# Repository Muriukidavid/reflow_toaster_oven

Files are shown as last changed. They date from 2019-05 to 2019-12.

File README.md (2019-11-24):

 
This is a reflow oven controller based on tinyK22 board with NXP K22P121M120SF7RM MCU.

The goal is to use the board on a breadboard for developing the firmware and design a custom board 

### Prototype Schematic
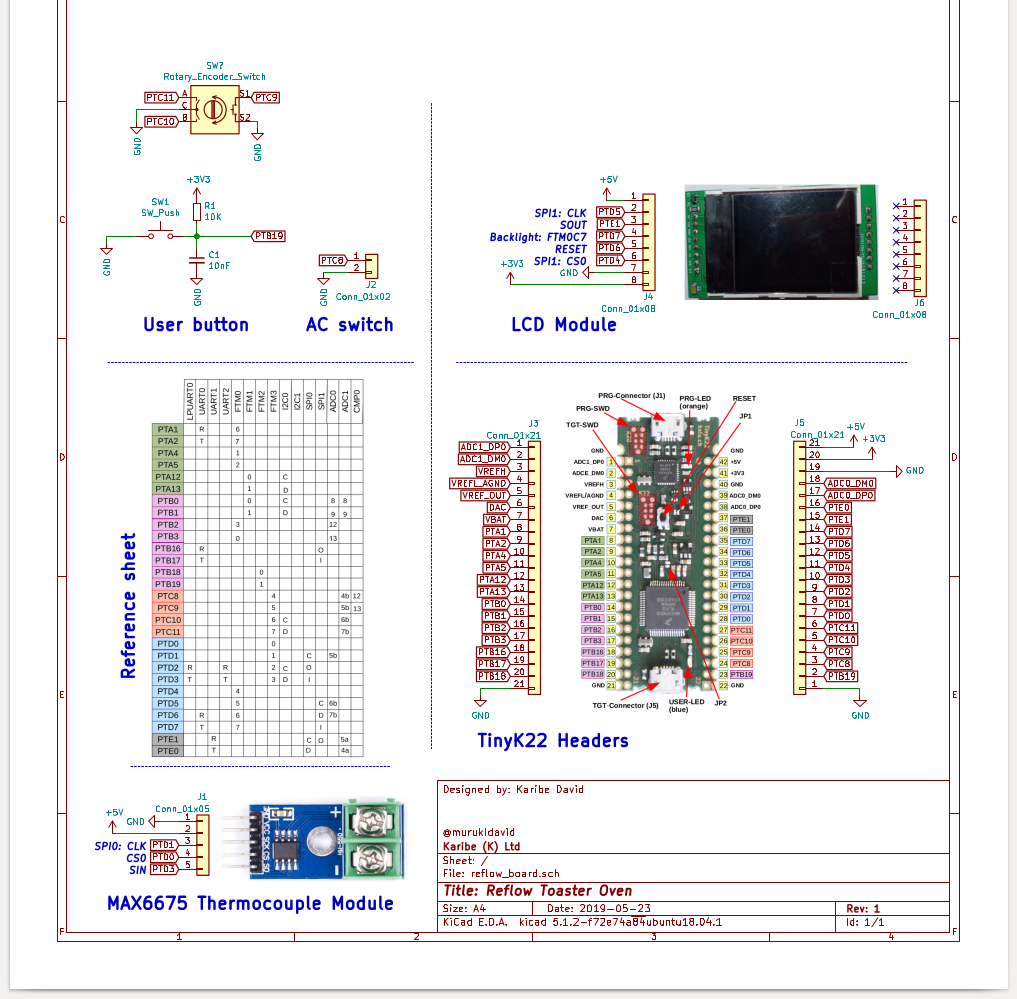
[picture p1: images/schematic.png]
The schematic


### Bread Board Prototype
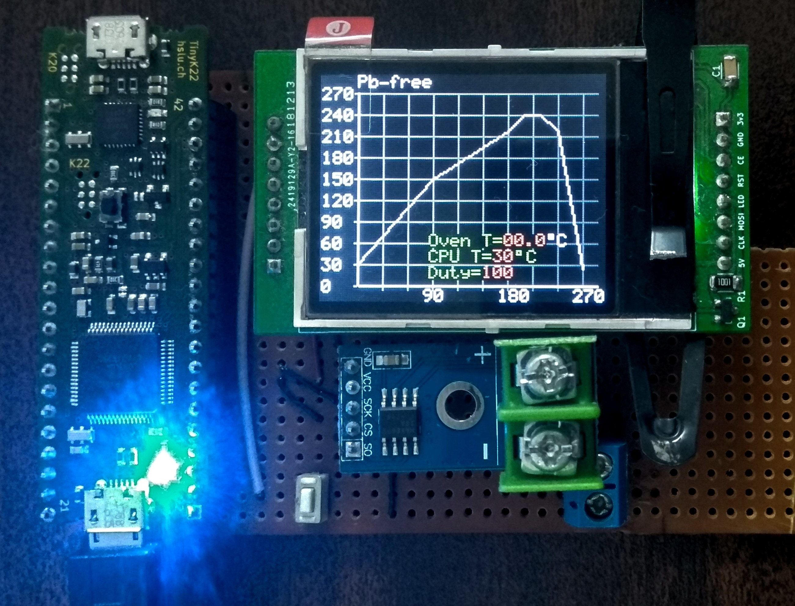
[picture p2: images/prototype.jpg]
The rough prototype testing board


### Custom Board Schematic
<!-- ![The schematic](images/schematic_custom.png)-->
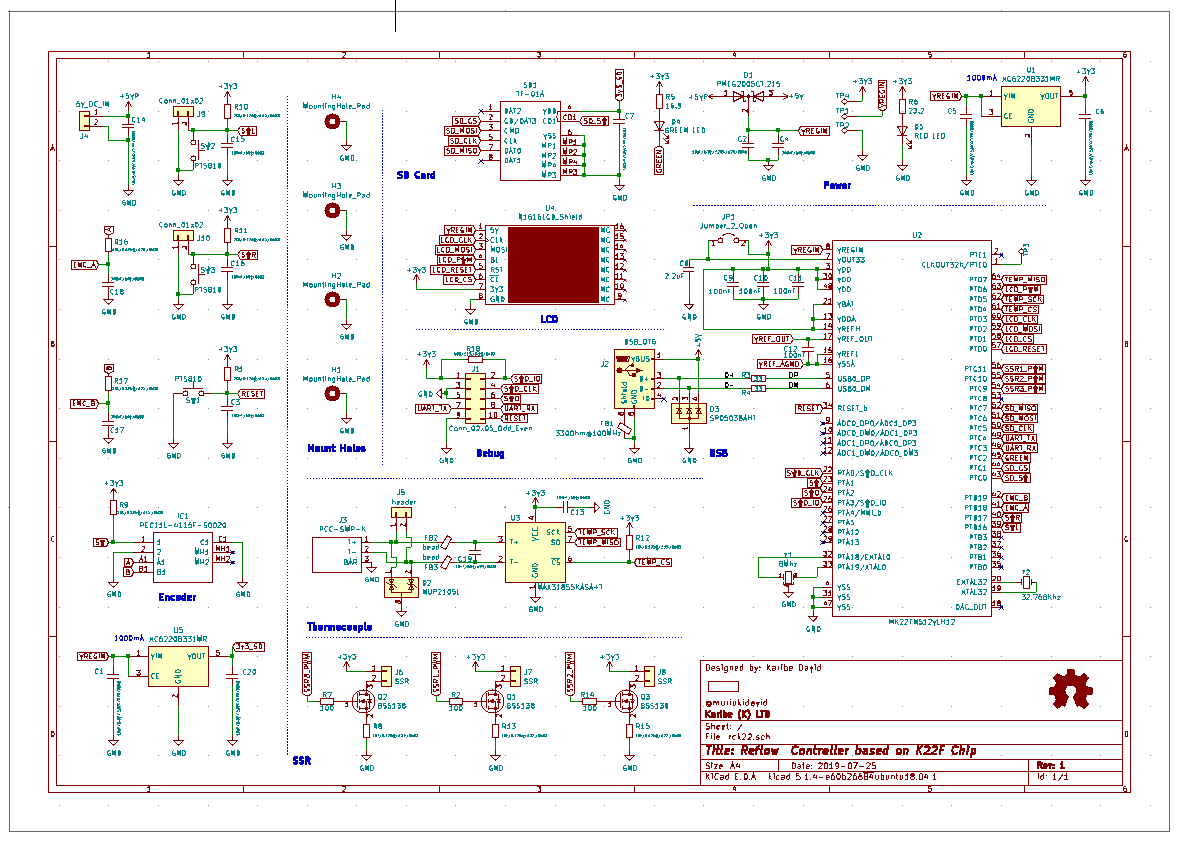
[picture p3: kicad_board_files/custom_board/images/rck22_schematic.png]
The custom board schematic


### Custom Board Top View 

A preview of the ongoing Custom board PCB design
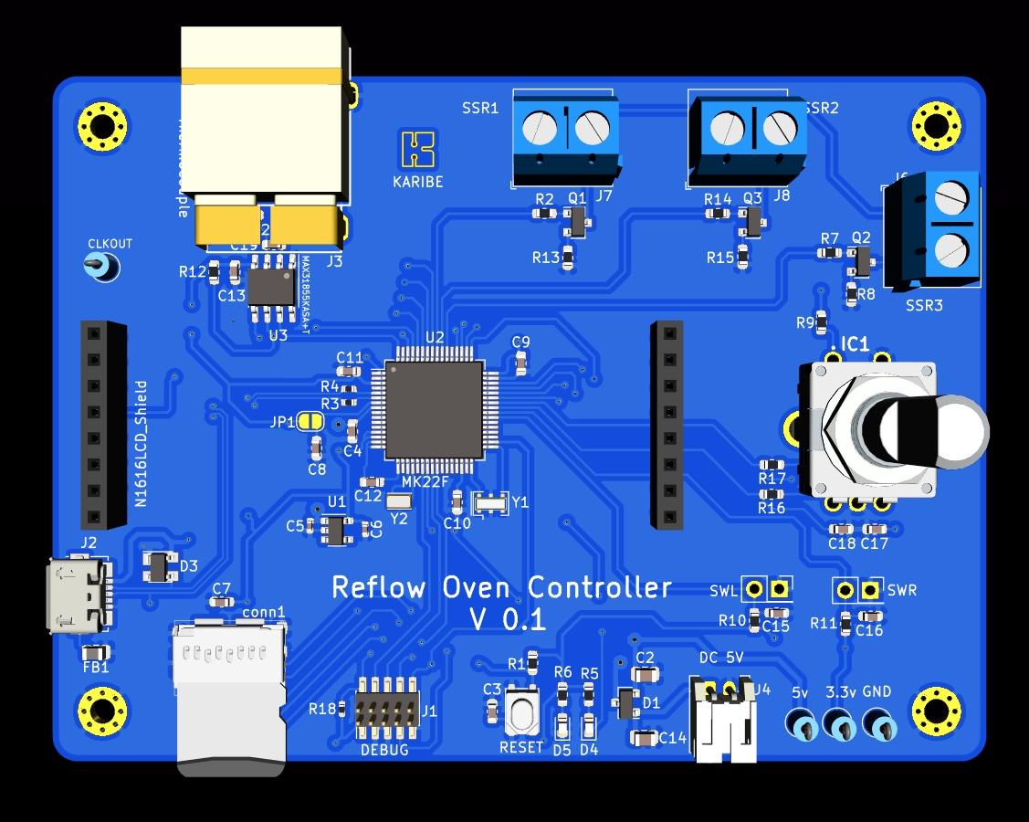
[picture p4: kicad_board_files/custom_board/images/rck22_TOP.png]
Board top view


A 3D preview of the current design
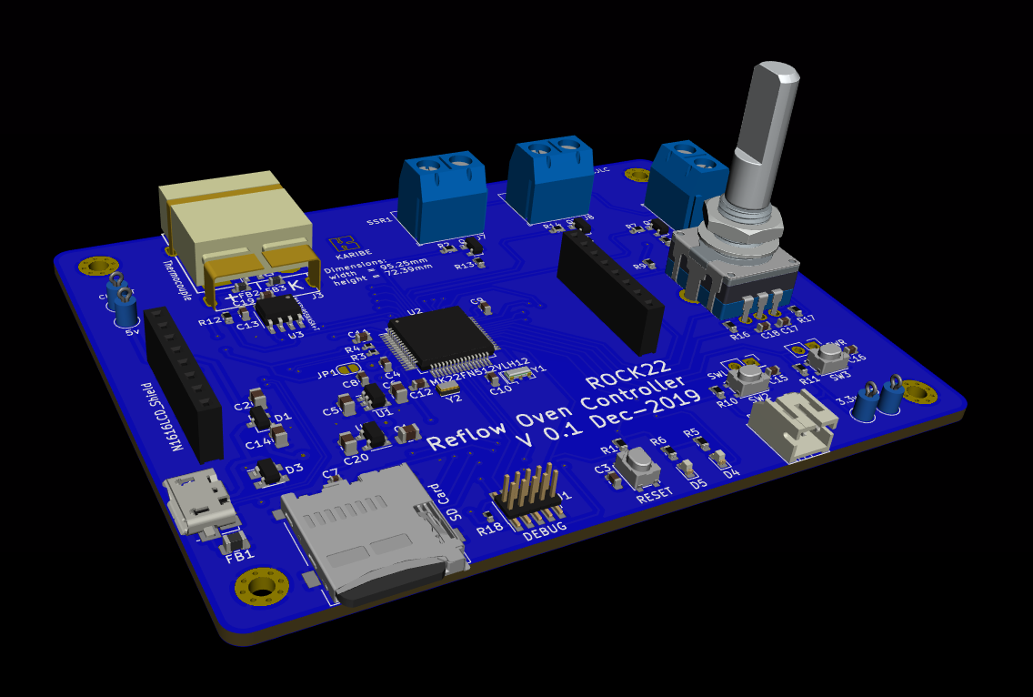
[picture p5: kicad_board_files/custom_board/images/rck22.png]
ISO 3D view PCB layout


### BOM
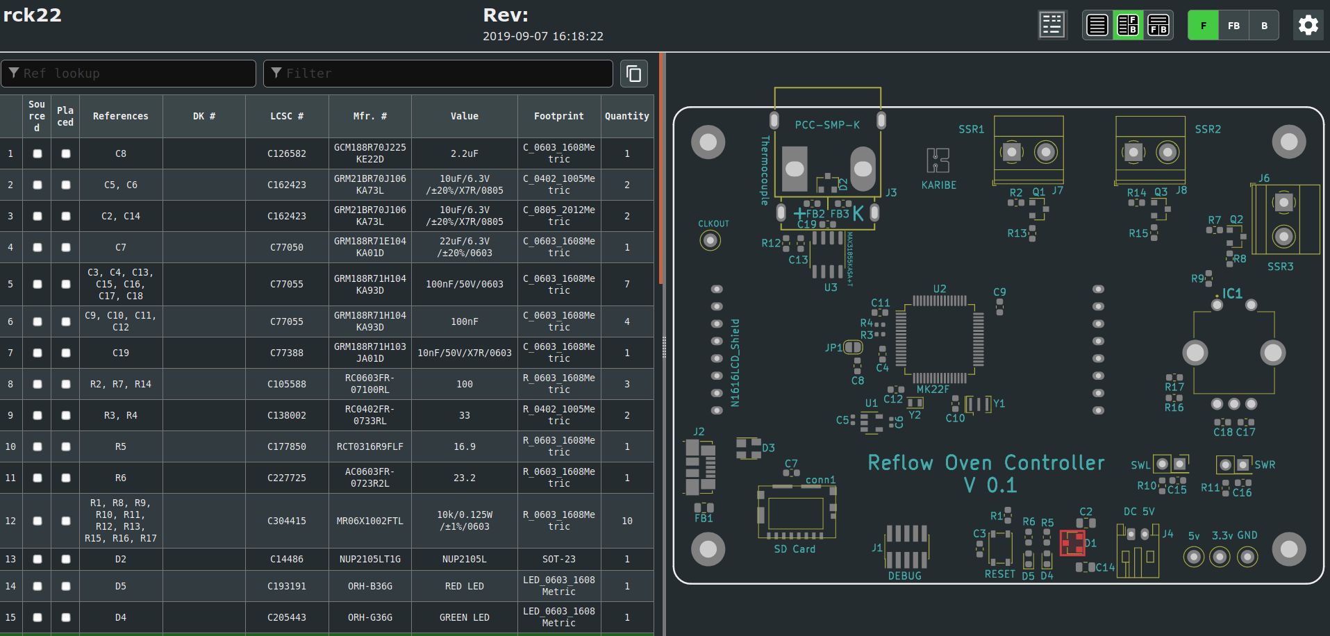
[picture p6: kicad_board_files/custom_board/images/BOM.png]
BOM
<a href="https://htmlpreview.github.io/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" rel="BOM">

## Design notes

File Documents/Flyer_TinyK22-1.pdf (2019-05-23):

# TinyK22

## Rev A

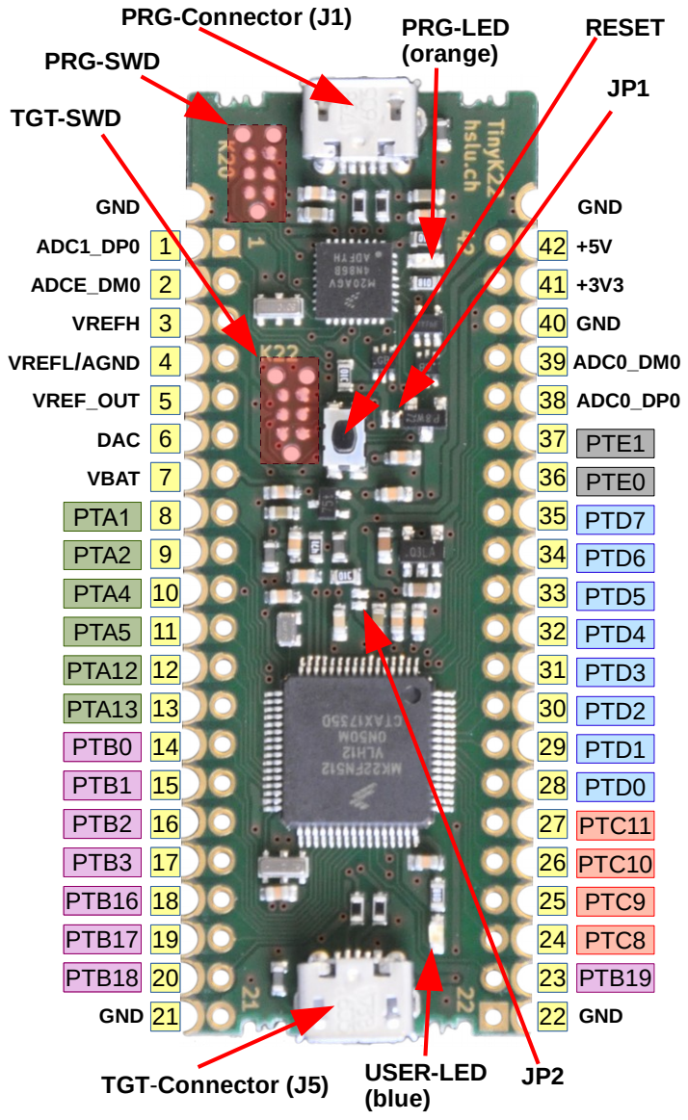
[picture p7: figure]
PTB0; PTB2; PTB1; PTB3; PTB17; PTB16; PTB18; ADC1_DP0; ADCE_DM0; VREFL; /AGND; VREFH; VREF_OUT; DAC; VBAT; PTA2 PTA4; PTA12; PTA5; PTA13; PTA1; GND; ADC0_DM0; ADC0_DP0; PTB19; PTC11 PTC10; PTC8; PTC9; PTD7 PTD6 PTD5; PTD3; PTD4; PTD2 PTD1 PTD0; PTE1 PTE0; TGT; -Connector (J5); PRG-Connector (J1); USER-LED (blue); PRG-LED (orange); RESET; TGT-SWD; PRG-SWD

# TinyK22

## Rev A

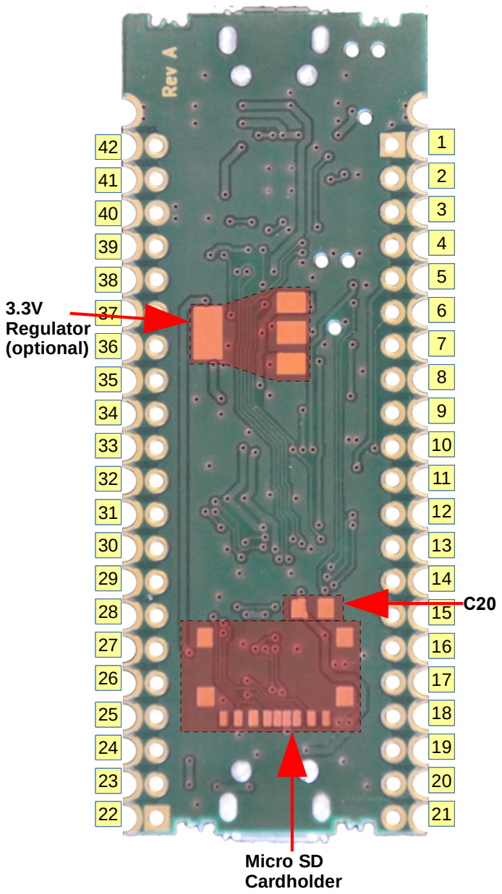
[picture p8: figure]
3.3V Regulator (optional); Micro SD Cardholder

PTA1 | R | 6
PTA2 | T
PTA4

PTA12

PTA5

PTA13

PTE1 | R | | 5a
PTE0 | T | D | 4a

PTD7
PTD6
PTD5

PTD3

PTD4

PTD2
PTD1

PTC11

PTD0

PTC10

PTC9

PTB19

LPUART0
UART0
FTM0
FTM1

FTM3
ADC0

ADC1

CMP0

UART1

UART2
FTM2
I2C0

I2C1

FTM2
SPI0

SPI1

CMP0

PTB0

PTB2 | 3 | 12 0 13
PTB3

PTB1

PTB17

PTB16

PTB18

PTD7
PTD6

PTD3
PTD2
PTD1
PTD0

PTD7
PTD6

PTD3

PTD2
PTD16

PTD5

PTD1

PTD0

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
PTC8
4 | 4b 5 | 5b 6 | 6b 7 | 7b

PTD7

PTD5

PTD2

PTD4

01 | 5b

R

R

2
T

T

3
45 | 6b

R

6 | 7b
T

7

# CDCD IO

12
13
CD

C
CD
OI | CDI C | O

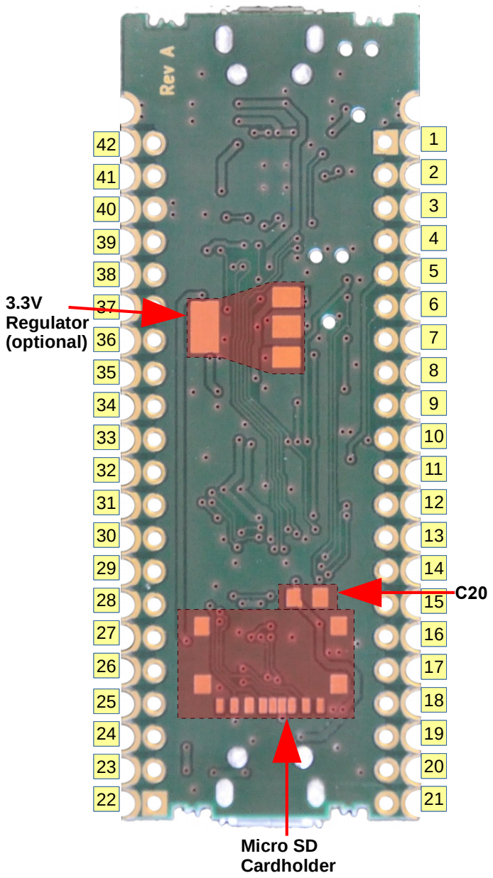
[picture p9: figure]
3.3V Regulator (optional); Micro SD Cardholder
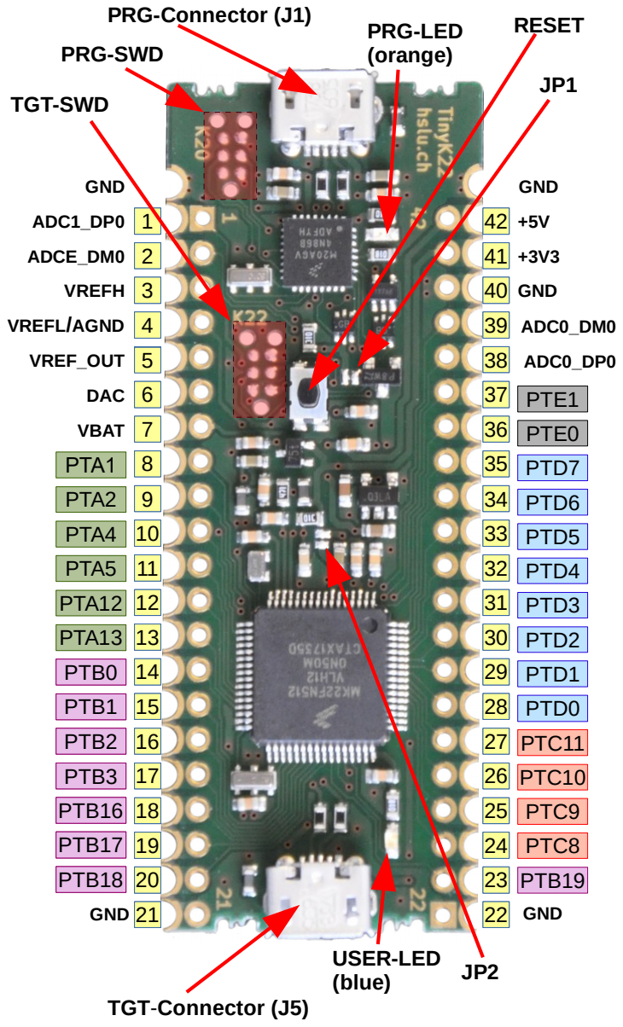
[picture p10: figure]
PTB0; PTB2; PTB1; PTB3; PTB17; PTB16; PTB18; ADC1_DP0; ADCE_DM0; VREFL; /AGND; VREFH; VREF_OUT; DAC; VBAT; PTA2 PTA4; PTA12; PTA5; PTA13; PTA1; GND; PTB19; PTC11 PTC10; PTC8; PTC9; PTD7; PTD6 PTD5; PTD3; PTD4; PTD2 PTD1 PTD0; PTE1 PTE0; TGT; -Connector (J5); PRG-Connector (J1); USER-LED (blue); PRG-LED (orange); RESET; ADC0_DM0; ADC0_DP0; TGT-SWD; PRG-SWD

PTA1 | R | 6
PTA2 | T
PTA4 | | 712

PTA12

PTA5

PTA13

PTE1

PTD7

PTE0

PTD6 PTD6 PTD6 PTD1 | | | | | C
PTD5 PTD2 | R | R | 2 | CD

PTD3

PTD4

PTD2
PTD1

PTC11

PTD0

PTC10

PTC9

PTB19

LPUART0
UART0
FTM0

FTM1

FTM3

ADC0

ADC1

CMP0

UART1

UART2
FTM2
I2C0
I2C1

FTM2
SPI0

SPI1

CMP0

PTB0

PTB2

PTB1

PTB3
PTB16 | RT
PTB17
PTB18

PTD7

PTD3
PTD2
PTD1
PTD0

PTD7

PTD3

PTD2
PTD16

PTD5

PTD0

TR | 5a

010

8

8
1
9

9
3 | 12 0 | 13

01

PTC8
4 | 4b 5 | 5b 6 | 6b 7 | 7b

PTD7

PTD5

PTD4

01 | 5b

T

T

3
45 | 6b

R

6 | 7b
T

7

# CDCD IO

12
13
CD
OI | CDI C | O D | 4a

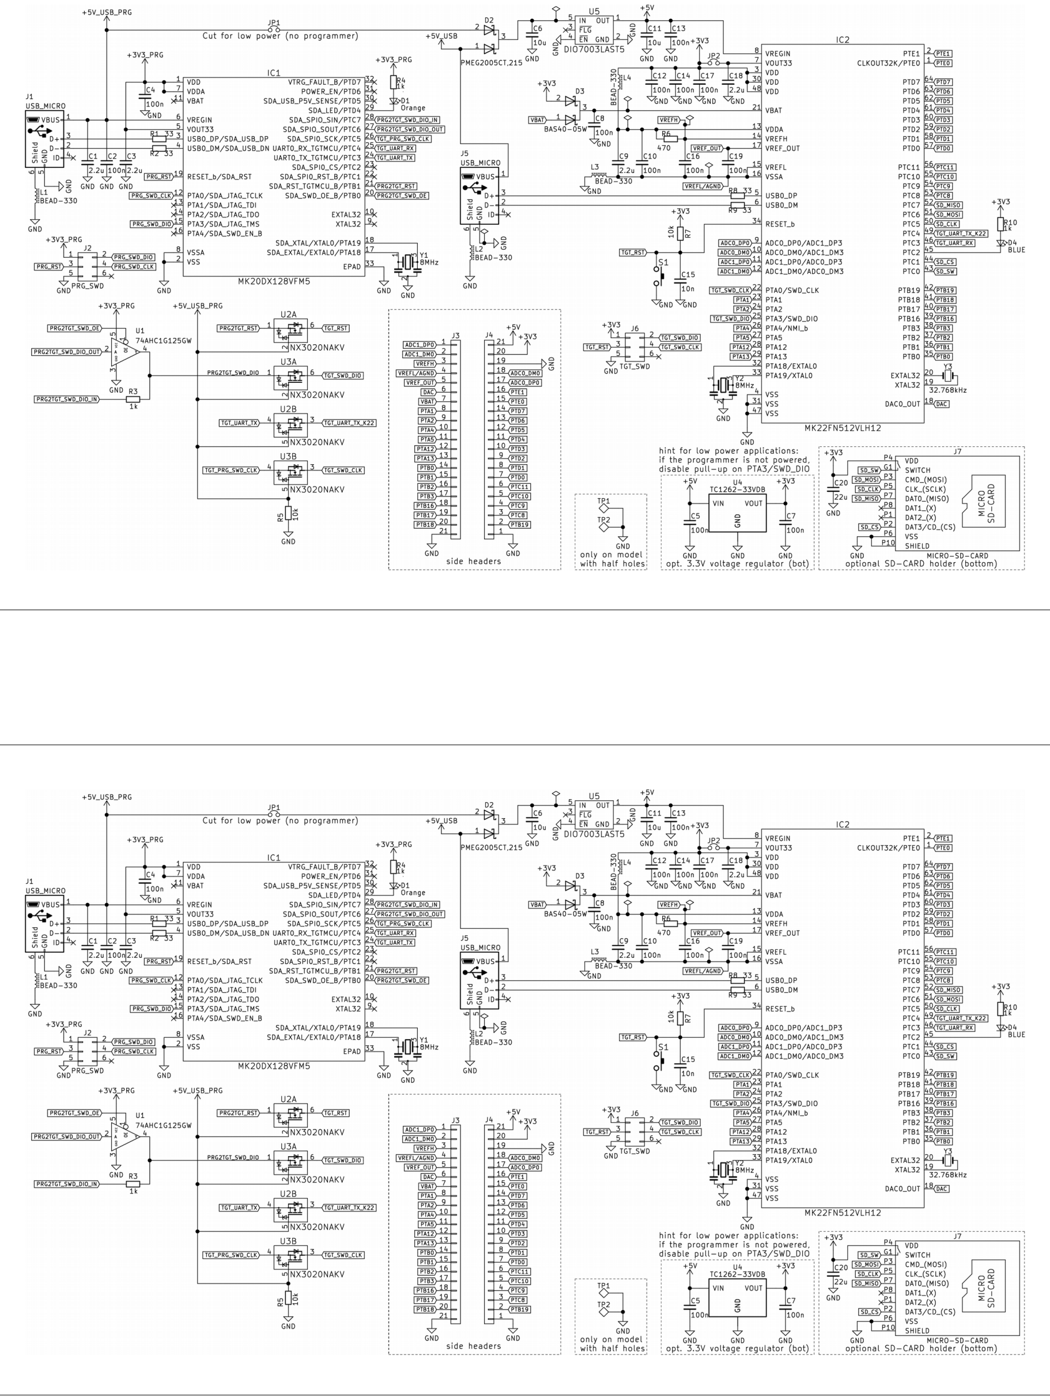
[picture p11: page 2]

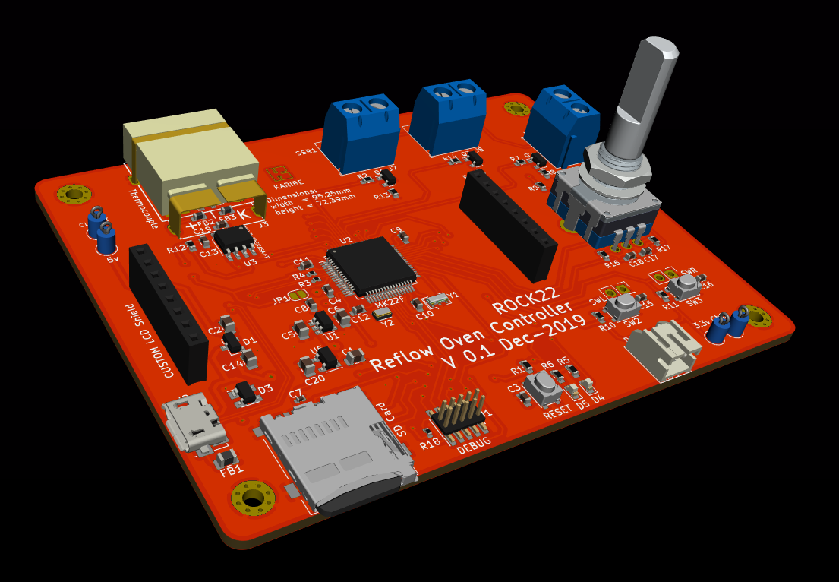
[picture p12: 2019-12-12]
kicad_board_files/custom_board/images/rck22_orange.png

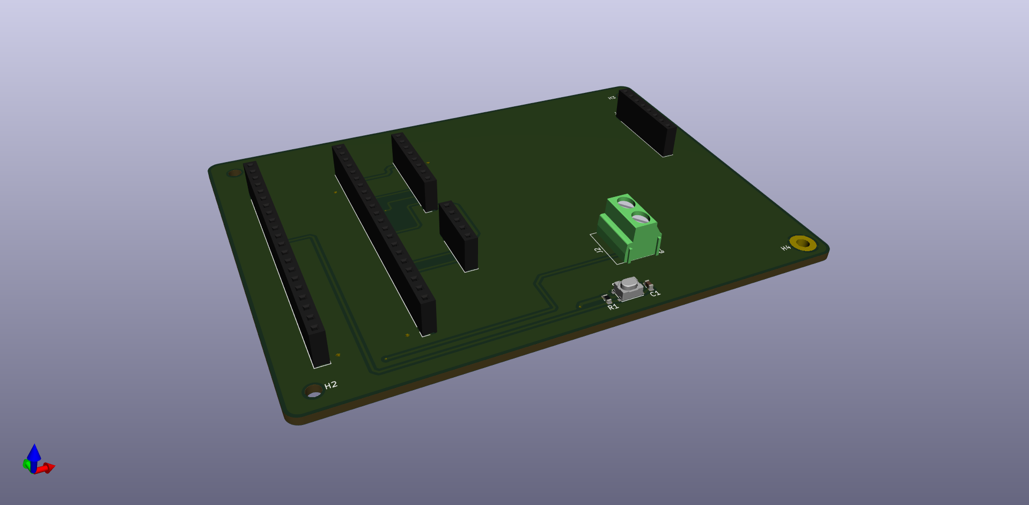
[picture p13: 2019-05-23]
kicad_board_files/tinyK22_board/images/reflow_board.png

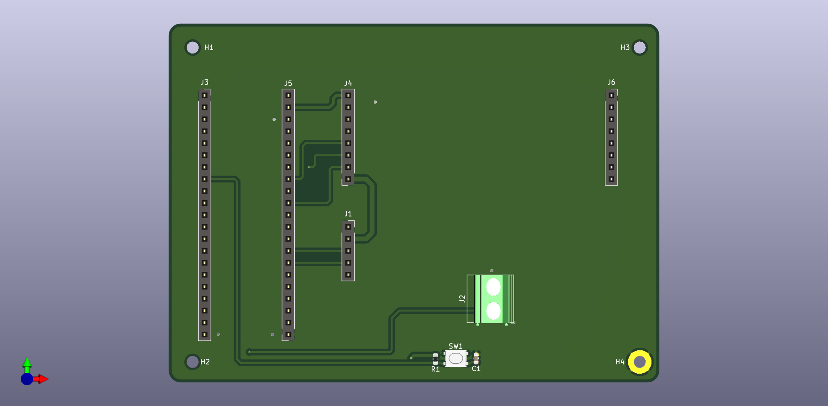
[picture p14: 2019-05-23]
kicad_board_files/tinyK22_board/images/reflow_board-TOP.png

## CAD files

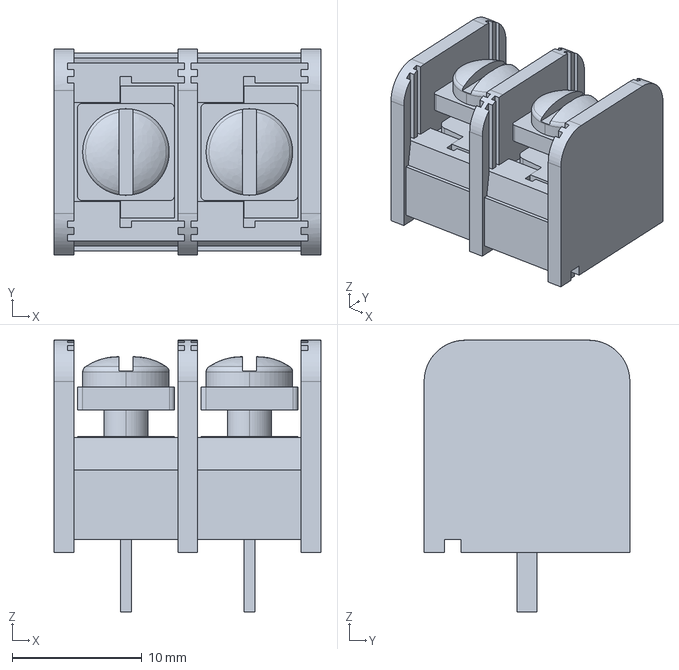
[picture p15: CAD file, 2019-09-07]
kicad_board_files/custom_board/3D_models/terminal_block_9.5mm.step
20.6 x 15.9 x 21.0 mm

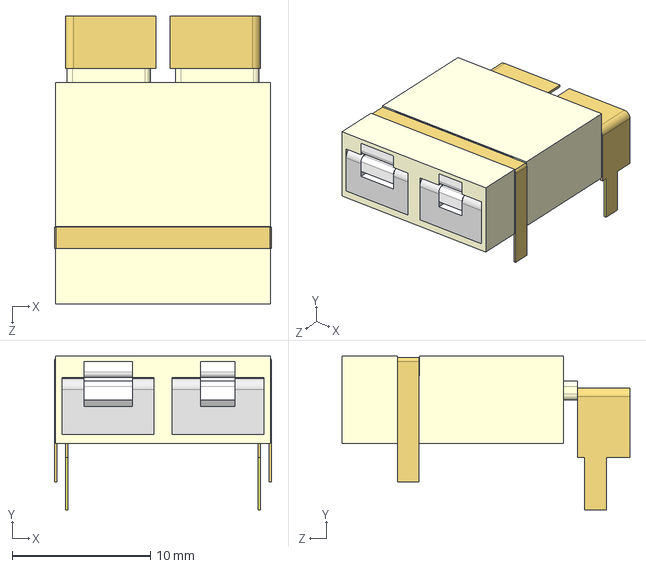
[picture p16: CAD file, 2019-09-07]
kicad_board_files/custom_board/3D_models/PCC-SMP-K.STEP
15.7 x 11.1 x 20.8 mm

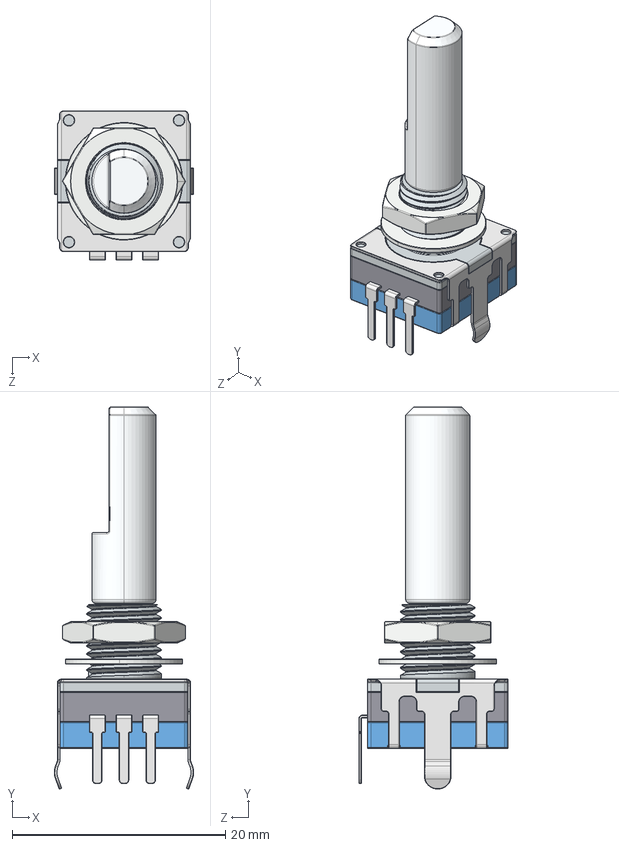
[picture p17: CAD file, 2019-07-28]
kicad_board_files/custom_board/3D_models/PEC11.step
13.1 x 35.8 x 14.0 mm
User Library-PEC11-4025F-N0024_PEC11_4025F_N0024_Standard
User Library-PEC11-4025F-N0024_Mutter-M7x075x10x2mm
User Library-PEC11-4025F-N0024_Unterlegscheibe-11x7x0.5_Standard

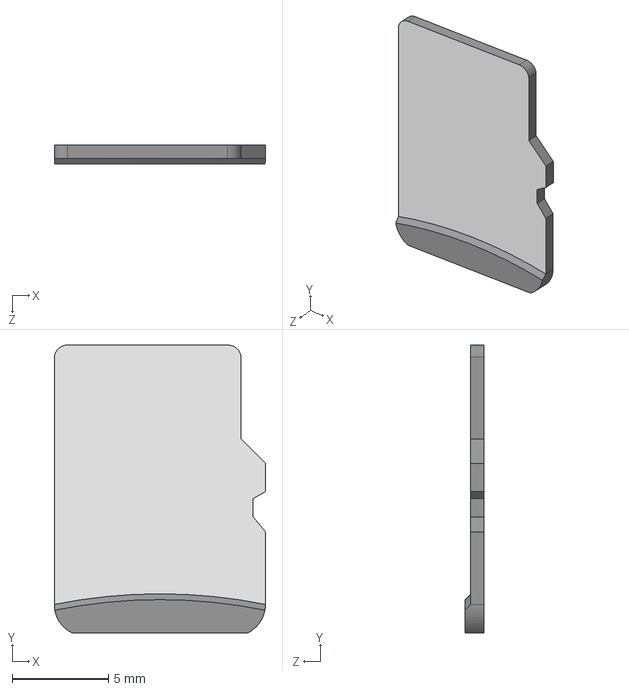
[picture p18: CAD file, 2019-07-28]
kicad_board_files/custom_board/3D_models/microsd_card.step
11.0 x 15.0 x 1.00 mm

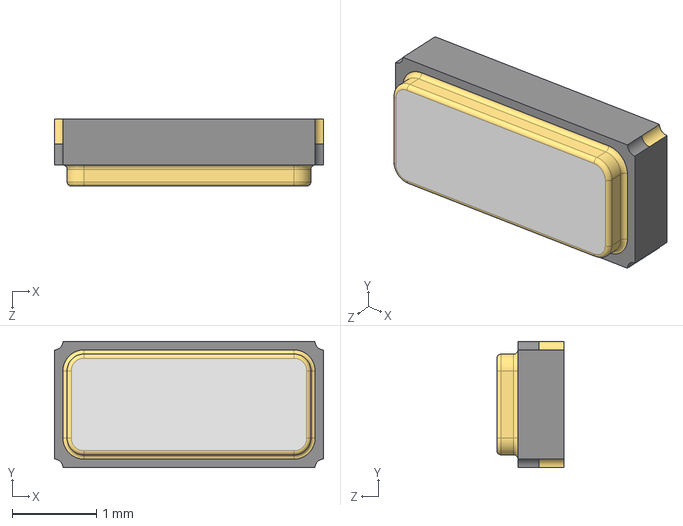
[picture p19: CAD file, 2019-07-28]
kicad_board_files/custom_board/3D_models/NX3215SA.STEP
3.20 x 1.50 x 0.8 mm

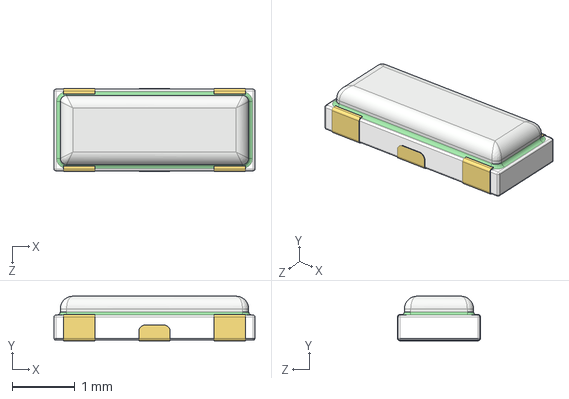
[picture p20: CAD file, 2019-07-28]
kicad_board_files/custom_board/3D_models/SMD_3P_3213.STEP
3.20 x 0.71 x 1.32 mm

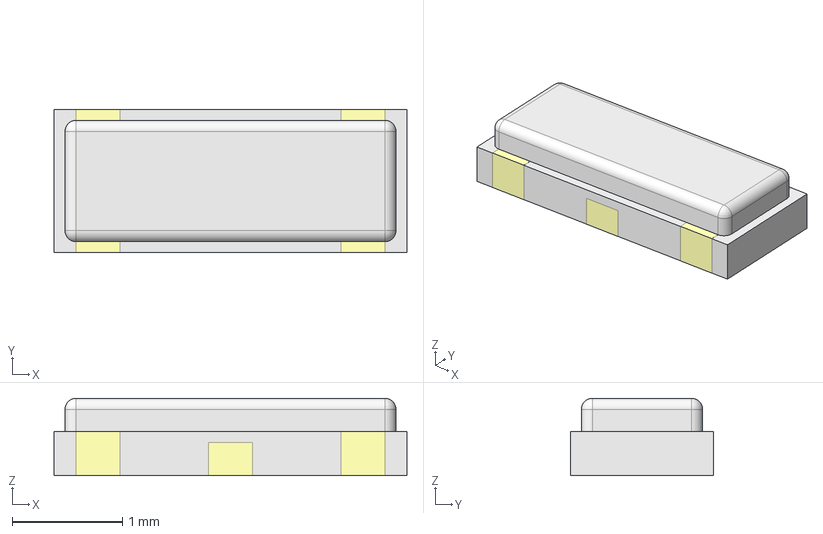
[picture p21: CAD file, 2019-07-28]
kicad_board_files/custom_board/3D_models/CSTCE.step
3.20 x 1.30 x 0.701 mm

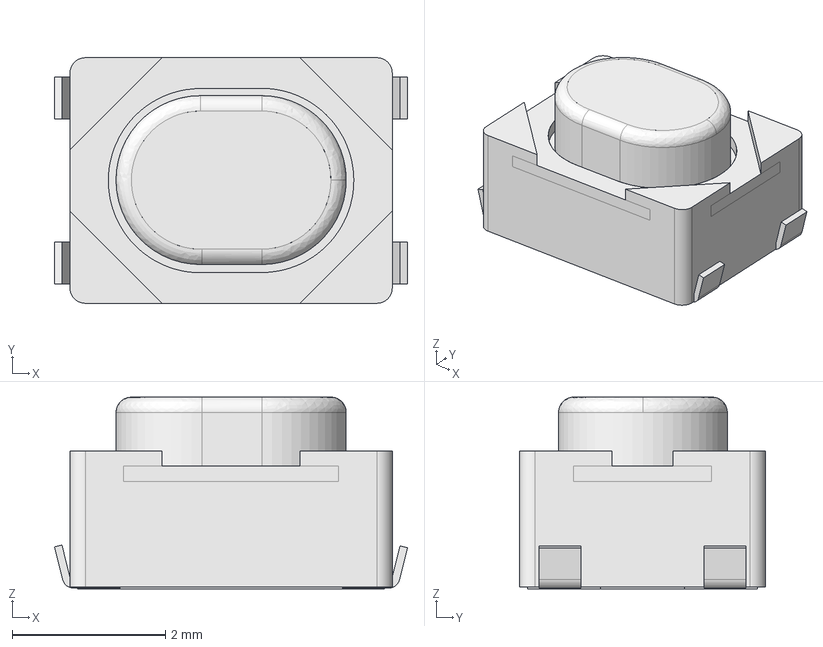
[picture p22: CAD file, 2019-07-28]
kicad_board_files/custom_board/3D_models/PTS810.step
4.60 x 3.20 x 2.50 mm

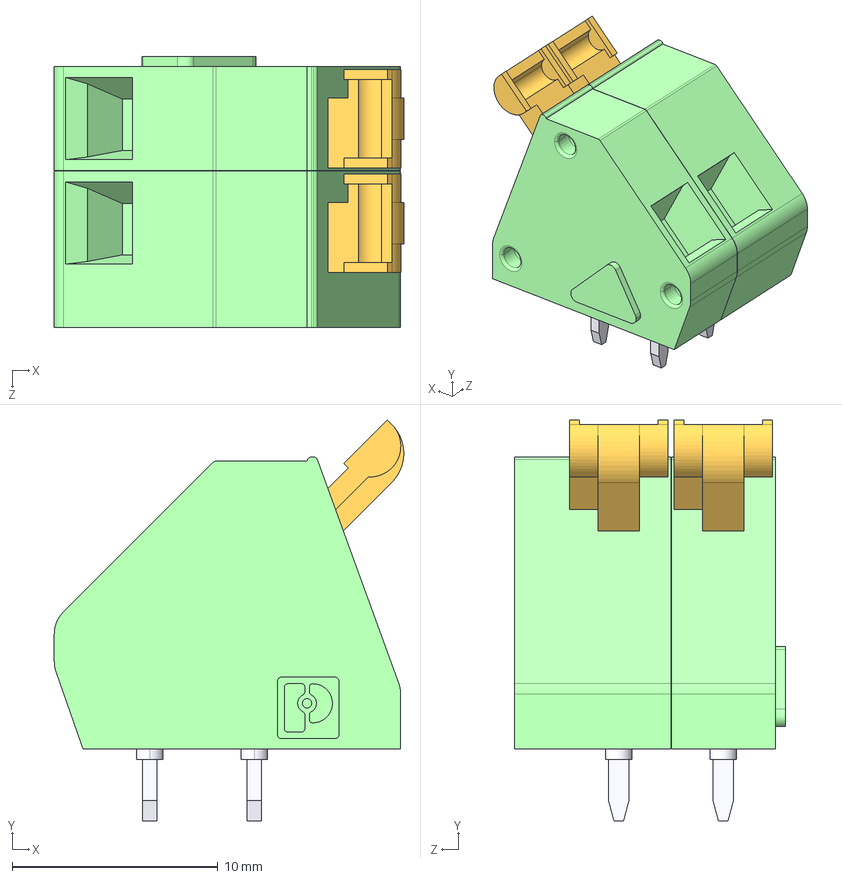
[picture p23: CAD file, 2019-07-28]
kicad_board_files/custom_board/3D_models/terminal_block.step
17.0 x 19.5 x 13.2 mm
User Library-1906158_zfkdsa_1_5-w-7_62-simple_2
User Library-1906158_zfkdsa_1_5-w-7_62-simple

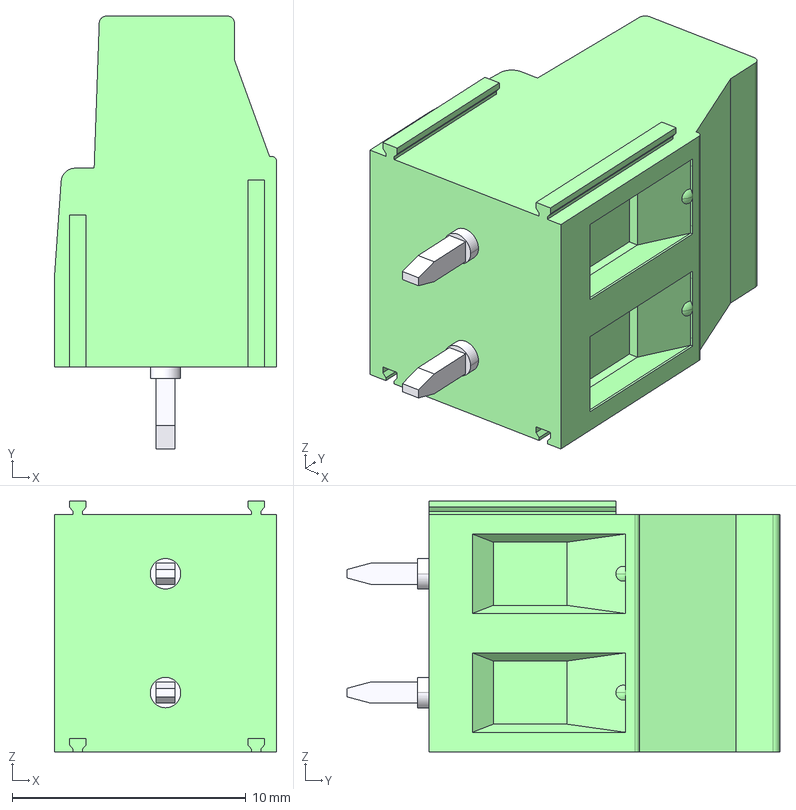
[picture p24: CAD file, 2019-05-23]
kicad_board_files/tinyK22_board/3D_models/87702032-3-38261/38261.stp
9.50 x 18.5 x 10.7 mm

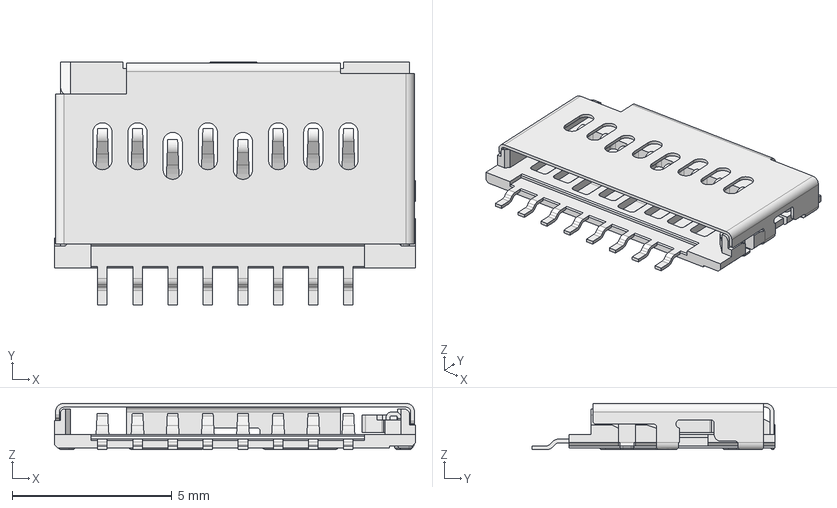
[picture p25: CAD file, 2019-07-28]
kicad_board_files/custom_board/3D_models/1051620101.step
11.3 x 7.60 x 1.45 mm

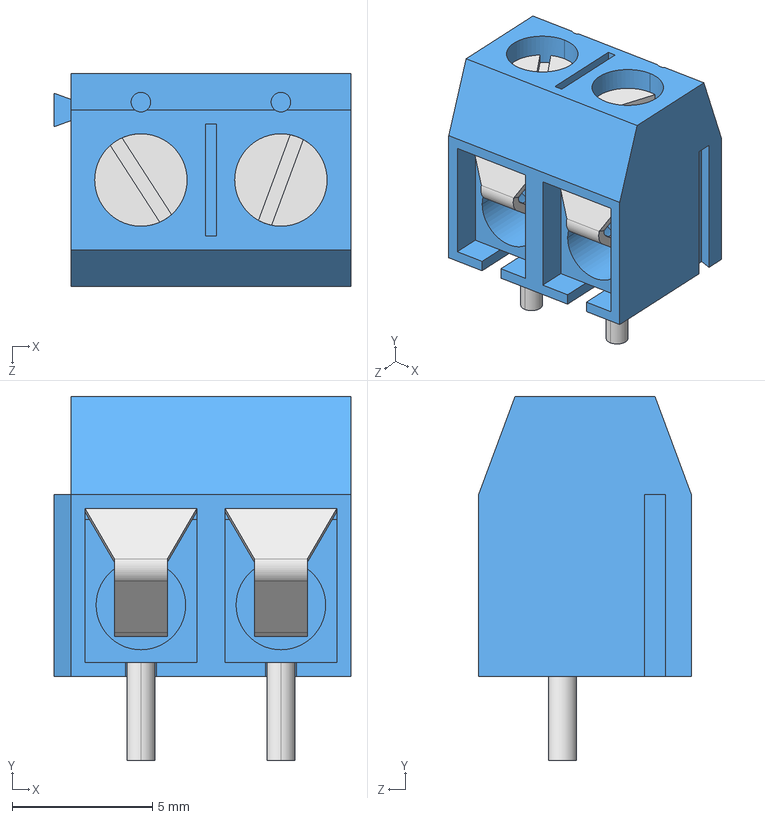
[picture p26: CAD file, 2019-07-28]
kicad_board_files/custom_board/3D_models/TerminalScrew.step
10.6 x 13.0 x 7.60 mm

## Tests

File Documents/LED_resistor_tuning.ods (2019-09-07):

forward current, Iled | 0.03 | Amperes
Supply voltage, Vcc | 3.3 | Volts
Power dissipation, Pled | 0.12 | Watts
Forward voltage, Vled | 2.8 | Volts
R=(Vcc-Vled)/Iled | 16.6666666666667 | Ohms

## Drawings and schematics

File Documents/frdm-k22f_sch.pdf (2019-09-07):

Table of Contents | Revisions & Change Log
X1 | Initial Draft

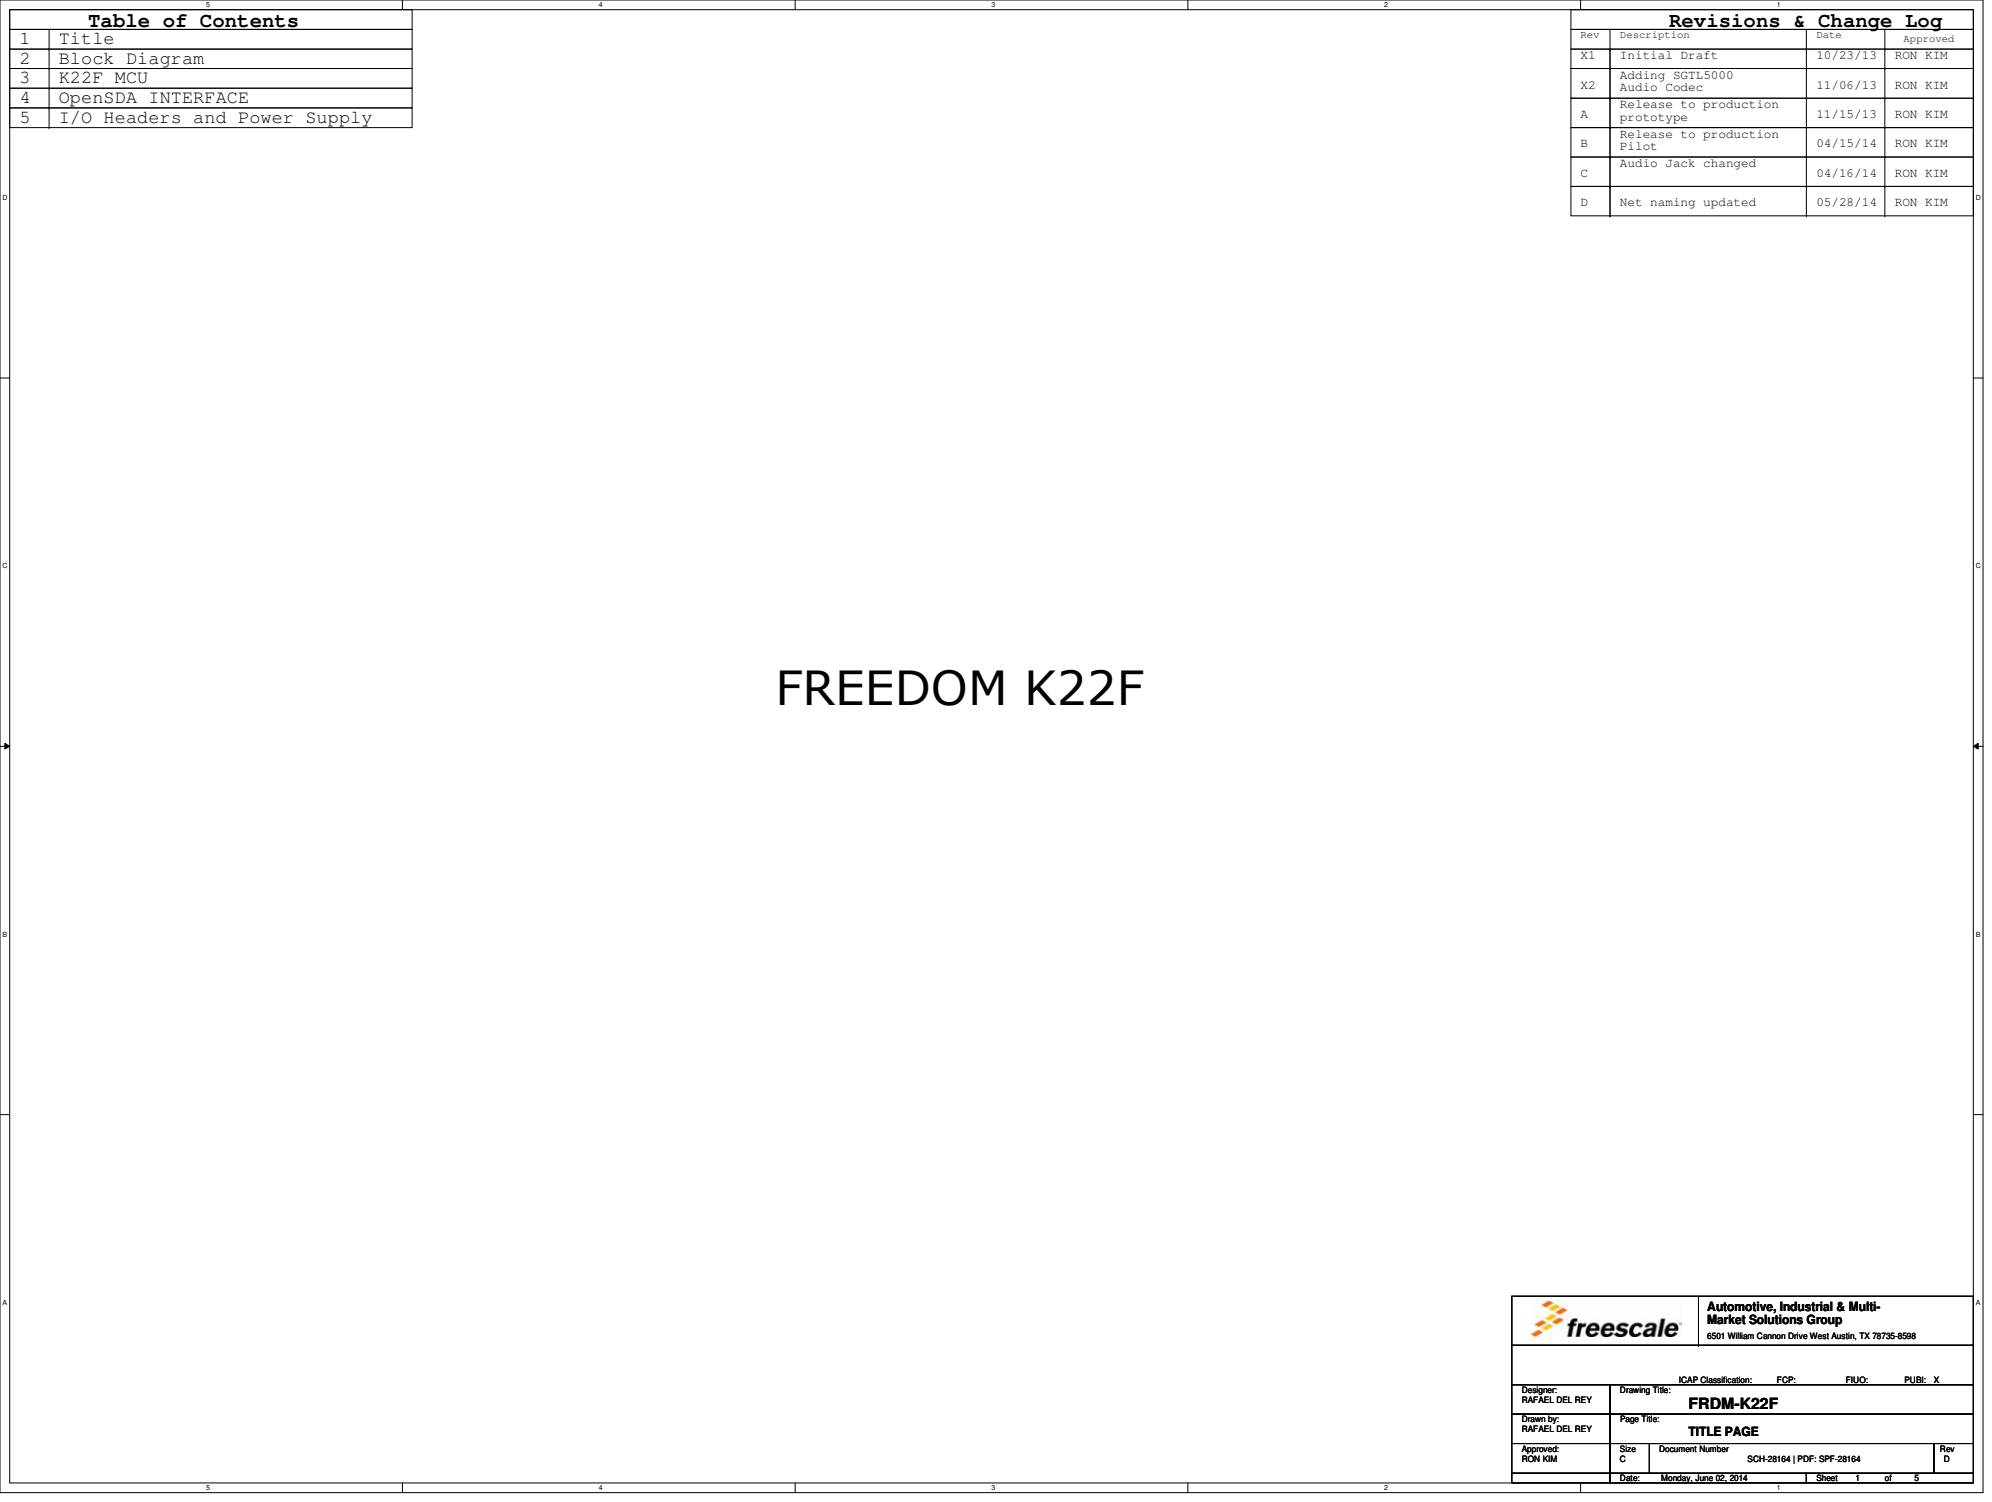
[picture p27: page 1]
Rev; Description; Approved RON KIM; Date; Block Diagram; Title; OpenSDA INTERFACE; K22F MCU; I/O Headers and Power Supply; FREEDOM K22F; Adding SGTL5000 Audio Codec; RON KIM; prototype; Pilot; Audio Jack changed; Net naming updated; Drawing Title:; Size; Document Number; Date:; Sheet; Page Title:; Approved:; ICAP Classification:; FCP:; FIUO:; PUBI:; SCH-28164 | PDF: SPF-28164; FRDM-K22F; Monday, June 02, 2014; TITLE PAGE; X Drawing Title: Size; Rev Date: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

Release to production

Automotive, Industrial & Multi-
Market Solutions Group

6501 William Cannon Drive West Austin, TX 78735-8598

Designer:
RAFAEL DEL REY

Drawn by:

# 1. Unless Otherwise Specified: All resistors are in ohms, 5%, 1/8 Watt

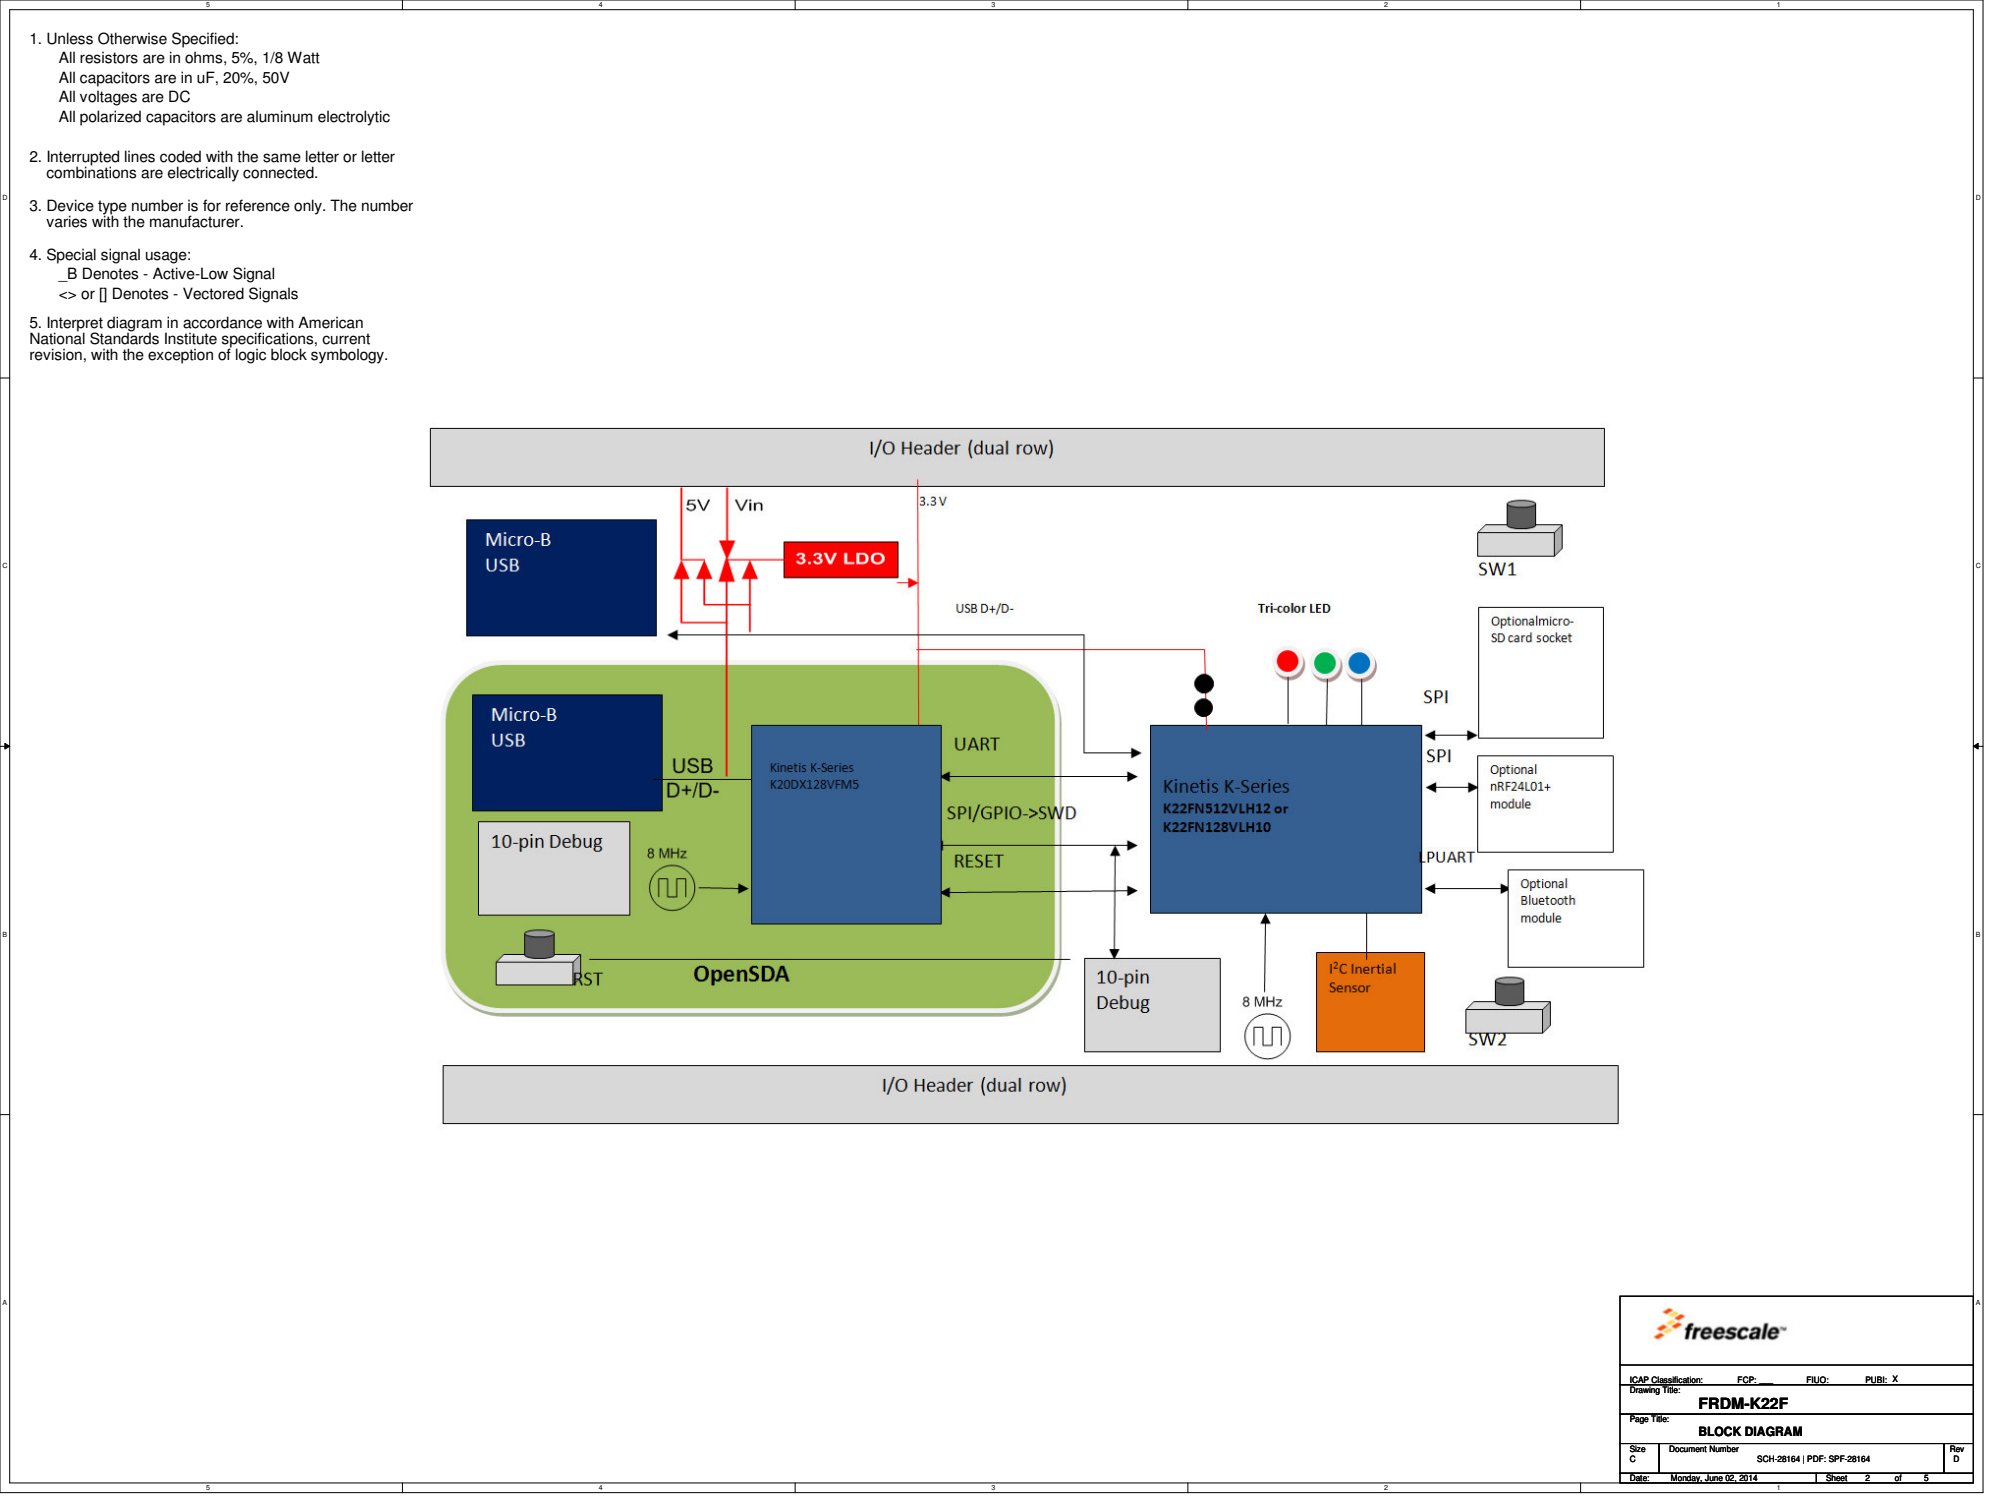
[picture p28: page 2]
Drawing Title:; ICAP Classification:; FCP:; FIUO:; PUBI:; FRDM-K22F; BLOCK DIAGRAM; X ___ Drawing Title:

All capacitors are in uF, 20%, 50V
All voltages are DC
All polarized capacitors are aluminum electrolytic

2. Interrupted lines coded with the same letter or letter
combinations are electrically connected.

3. Device type number is for reference only. The number
varies with the manufacturer.

4. Special signal usage:
_B Denotes - Active-Low Signal
<> or [] Denotes - Vectored Signals

5. Interpret diagram in accordance with American
National Standards Institute specifications, current
revision, with the exception of logic block symbology.

# K22F DECOUPLING CAPS

# K22F USB CONNECTOR

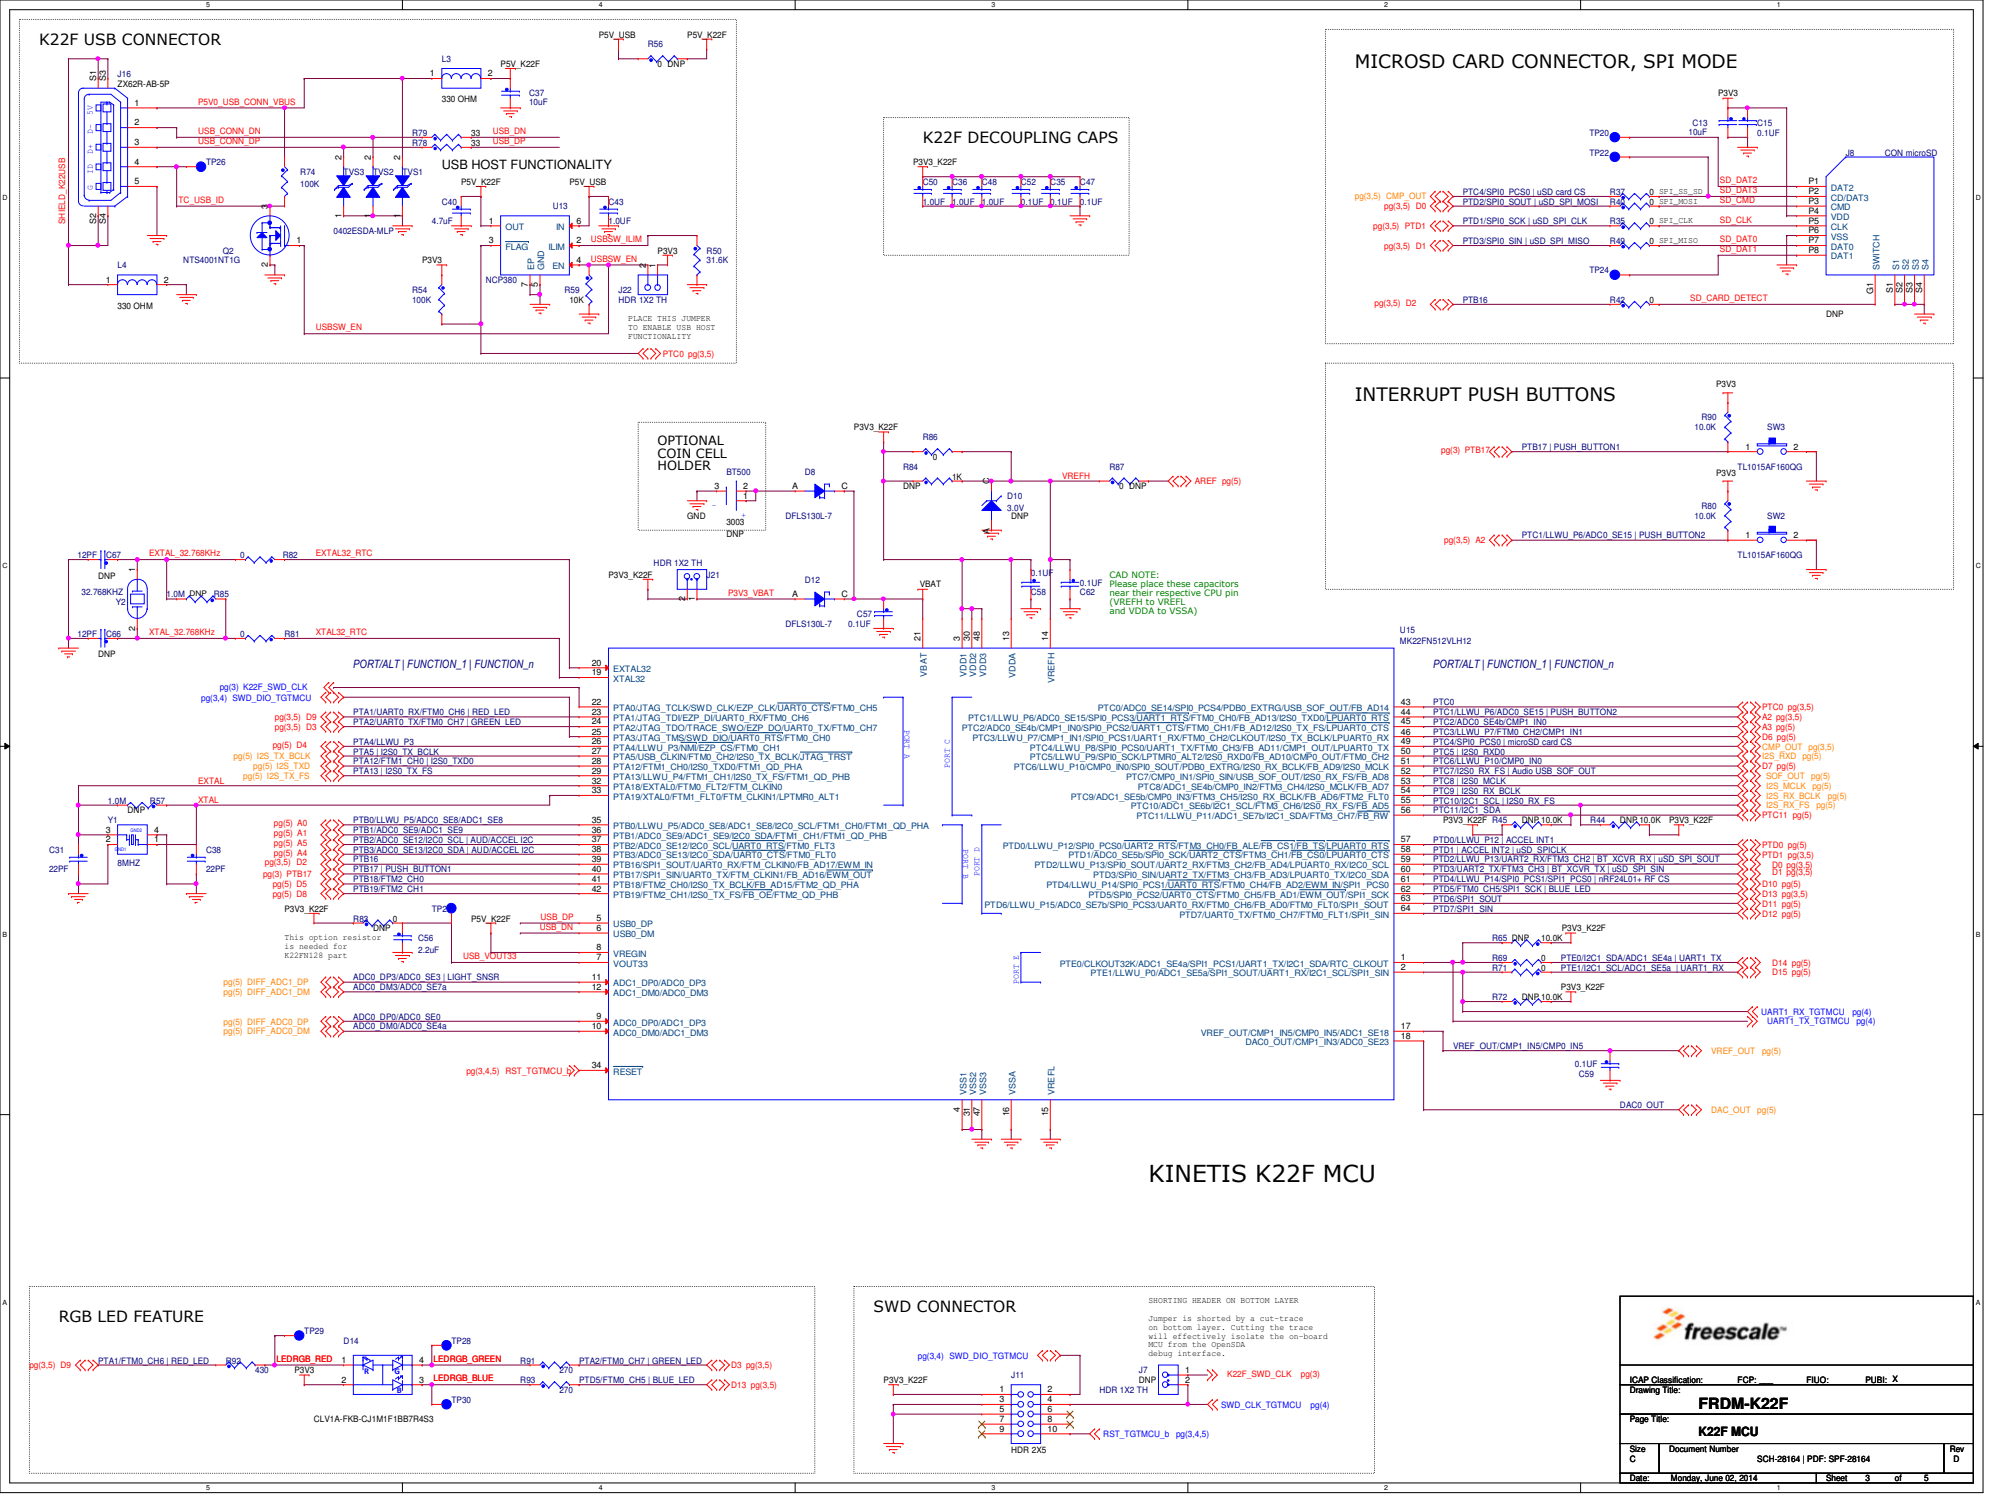
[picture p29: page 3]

MICROSD CARD CONNECTOR, SPI MODE

PLACE THIS JUMPER
TO ENABLE USB HOST
FUNCTIONALITY

CAD NOTE:
Please place these capacitors
near their respective CPU pin
(VREFH to VREFL
and VDDA to VSSA)

SHORTING HEADER ON BOTTOM LAYER

Jumper is shorted by a cut-trace
on bottom layer. Cutting the trace
will effectively isolate the on-board
MCU from the OpenSDA
debug interface.
DNP

# OpenSDA Interface

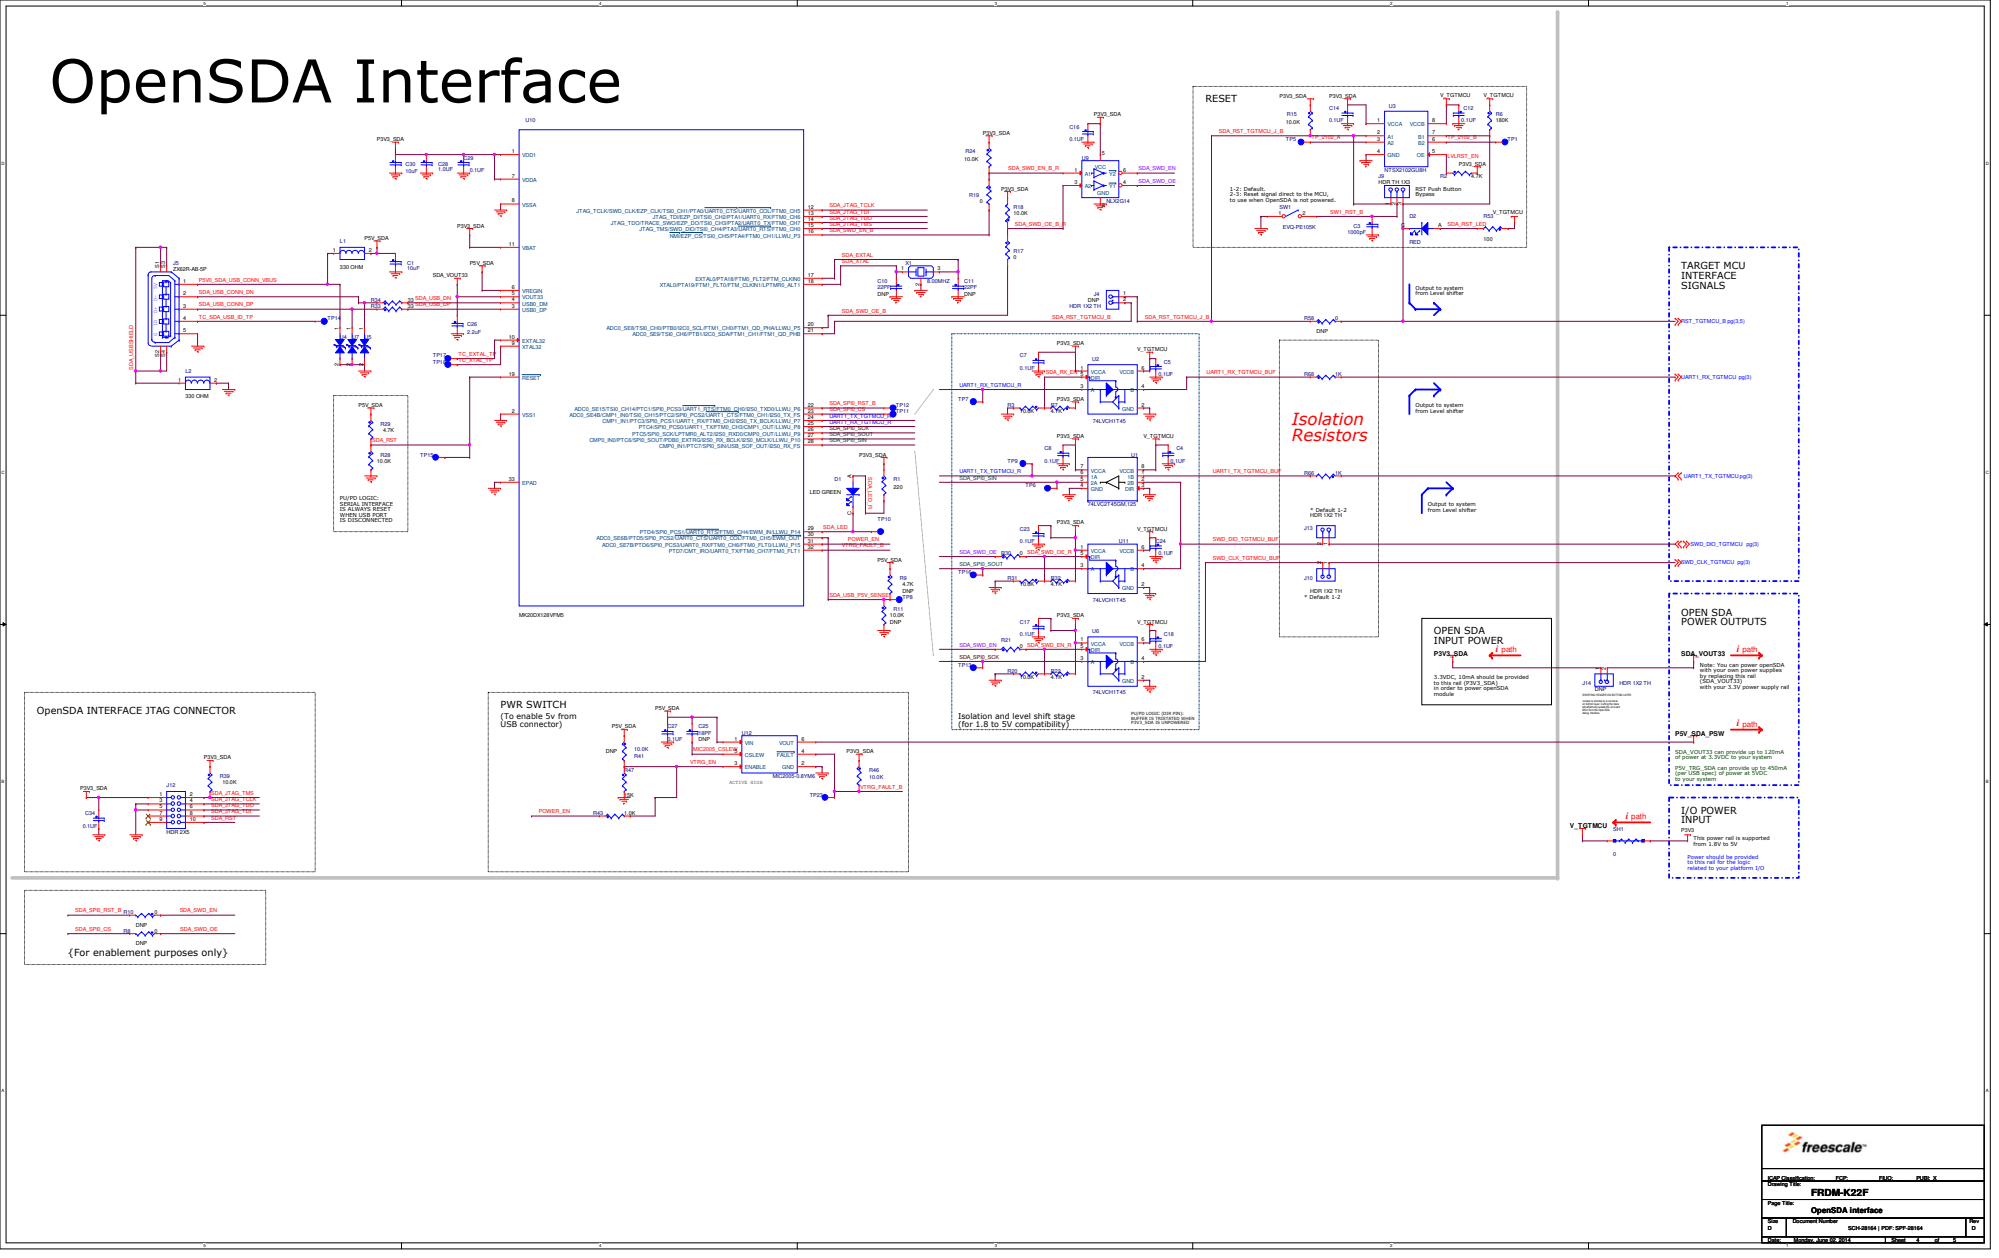
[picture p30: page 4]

1-2: Default.
2-3: Reset signal direct to the MCU,
to use when OpenSDA is not powered.

HW Designer: Rafael del Rey

3.3VDC, 10mA should be provided
to this rail (P3V3_SDA)
in order to power openSDA
module

Note: You can power openSDA
with your own power supplies
by replacing this rail
(SDA_VOUT33)
with your 3.3V power supply rail

SHORTING HEADER ON BOTTOM LAYER

OpenSDA INTERFACE JTAG CONNECTOR

PWR SWITCH
P3V3_SDA IS UNPOWERED (To enable 5v from USB connector)

Isolation and level shift stage
(for 1.8 to 5V compatibility)

PU/PD LOGIC (DIR PIN):
BUFFER IS TRISTATED WHEN

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

SDA_VOUT33 can provide up to 120mA
of power at 3.3VDC to your system

P5V_TRG_SDA can provide up to 450mA
(per USB spec) of power at 5VDC
to your system

This power rail is supported
from 1.8V to 5V

Power should be provided
to this rail for the logic
related to your platform I/O

{For enablement purposes only}

# FREEDOM PLATFORM COMPATIBILITY HEADERS

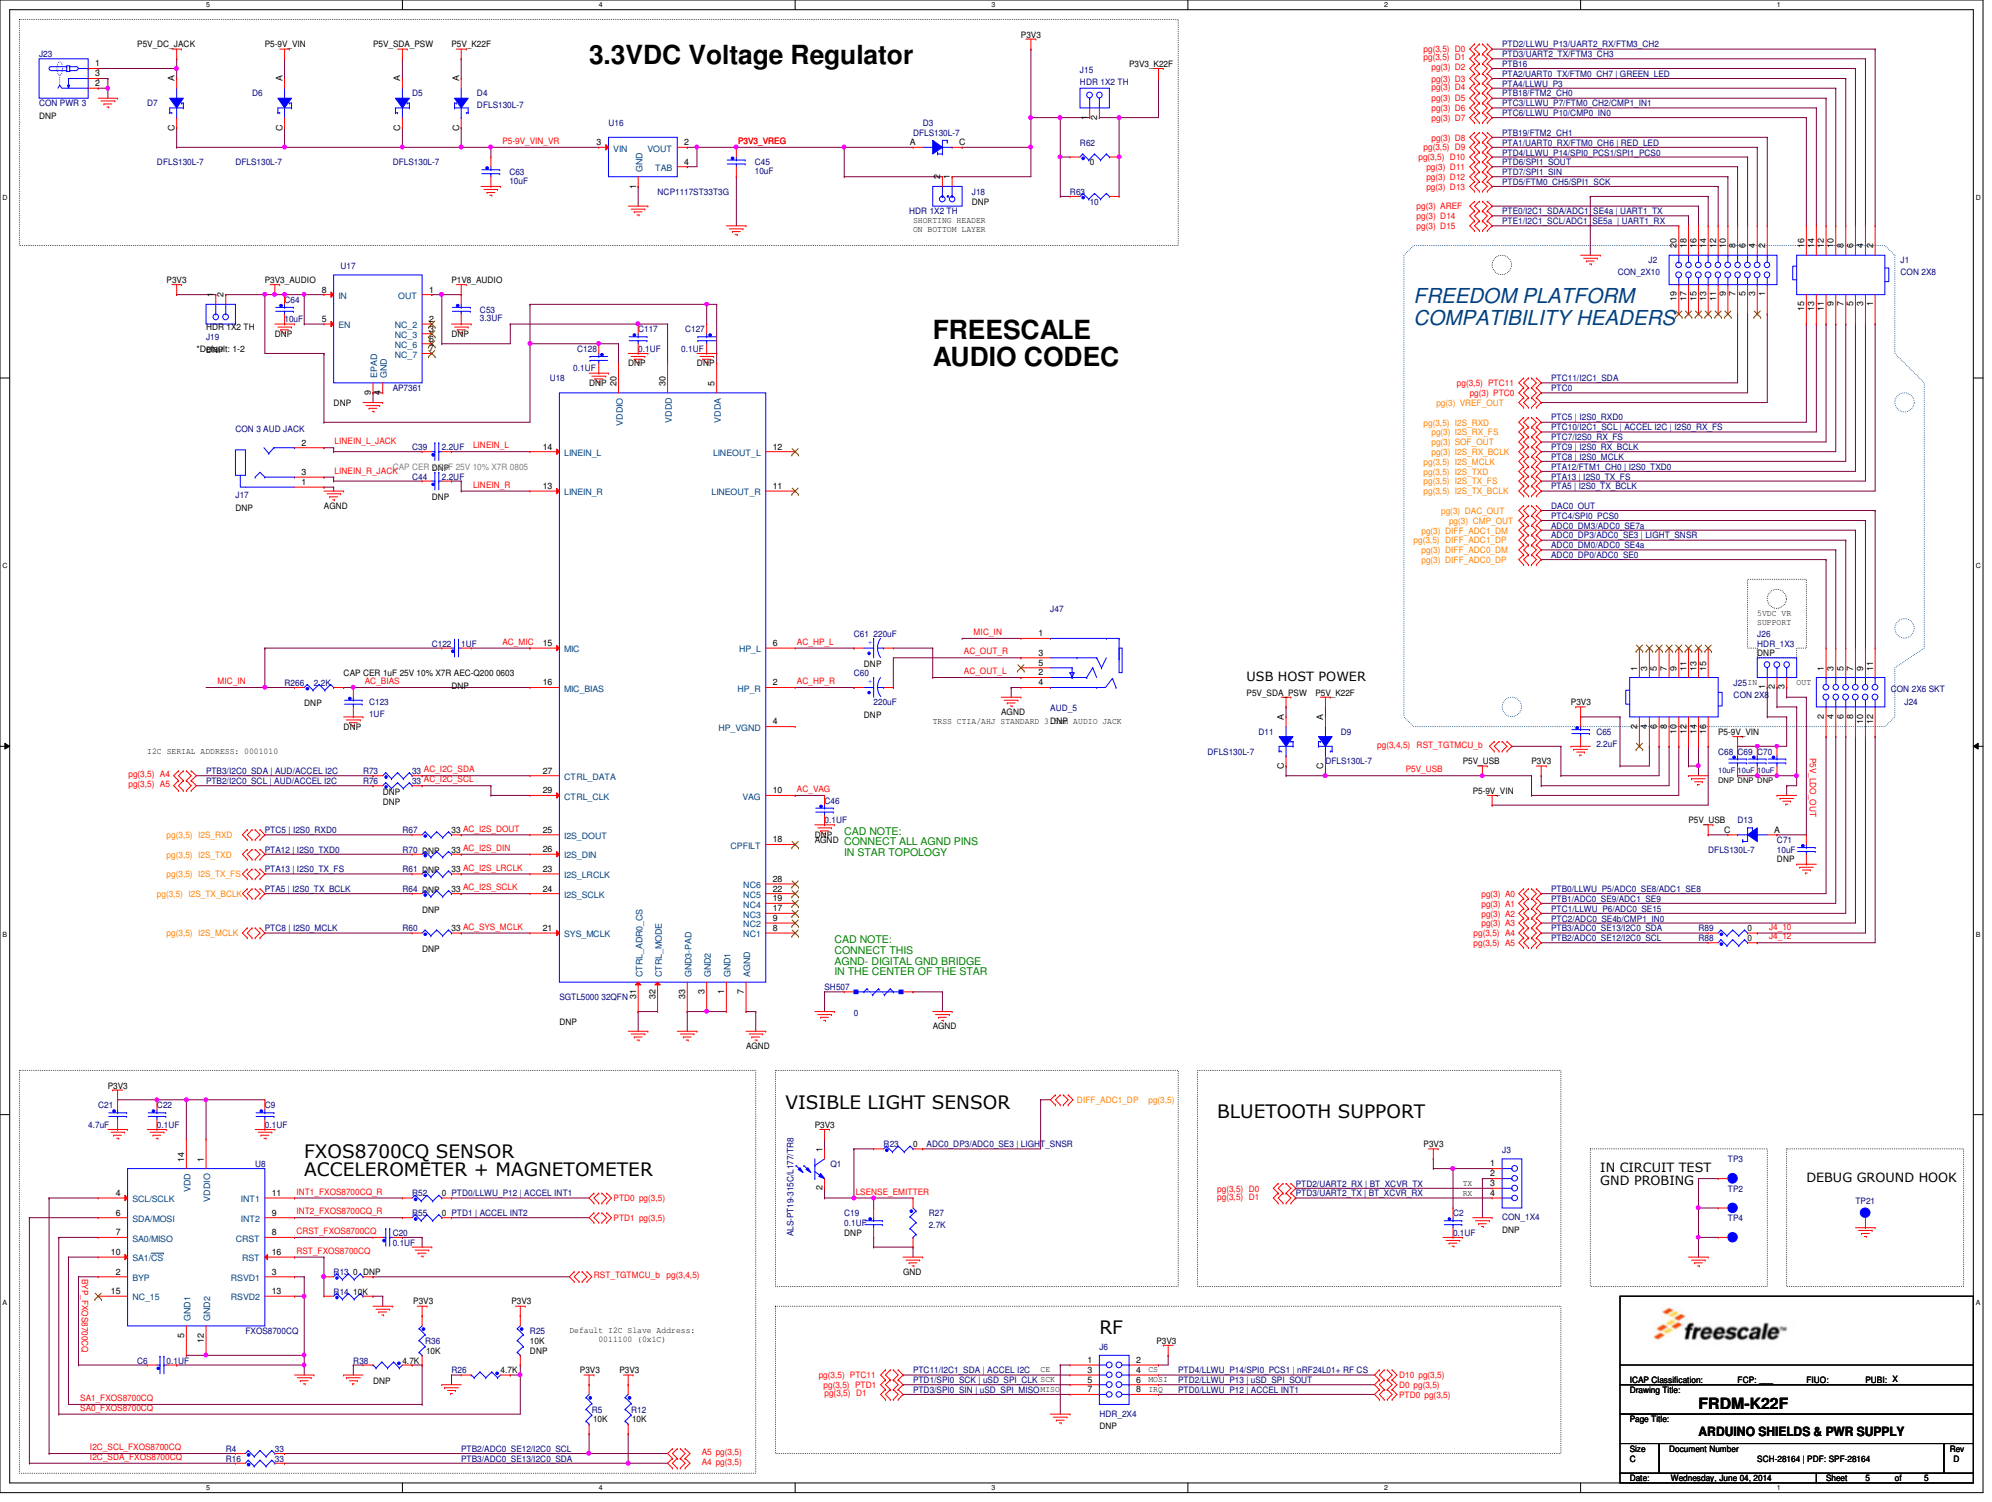
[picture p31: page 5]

TRSS CTIA/AHJ STANDARD 3.5mm AUDIO JACK

CAD NOTE:
CONNECT ALL AGND PINS
IN STAR TOPOLOGY

CONNECT THIS
AGND- DIGITAL GND BRIDGE
IN THE CENTER OF THE STAR

ARDUINO SHIELDS & PWR SUPPLY

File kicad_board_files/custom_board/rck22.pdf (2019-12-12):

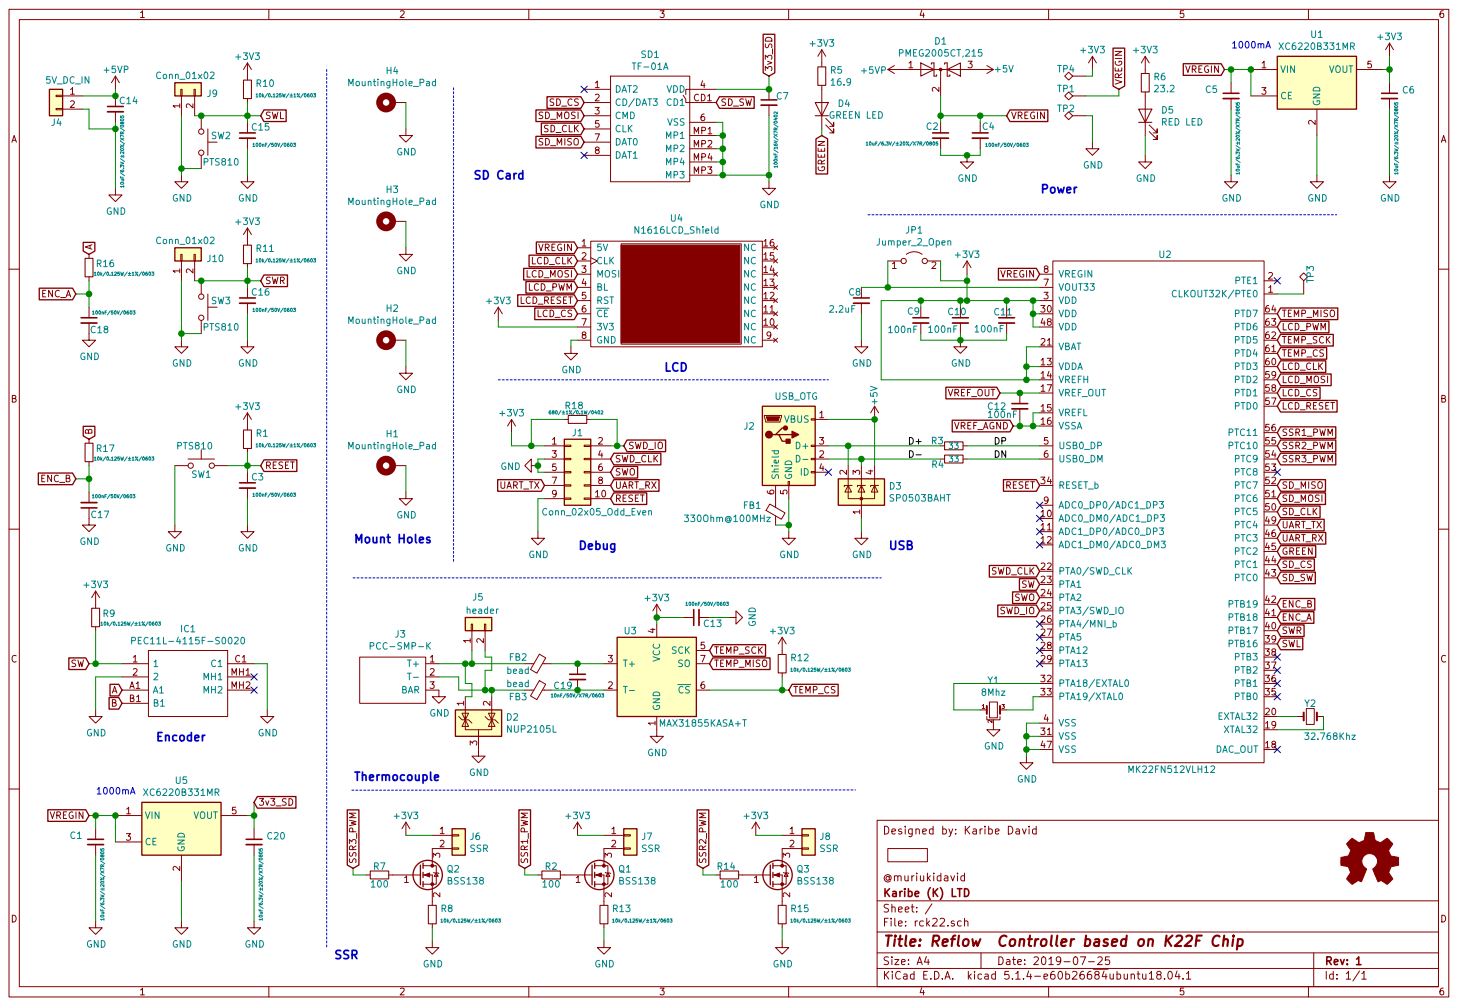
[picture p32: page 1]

4 SCK 5 CS 6 SO 7 U3 MAX31855KASA+T GND

Designed by: Karibe David

@muriukidavid
File: rck22.sch Sheet: / Karibe (K) LTD

Id: 1/1 Title: Reflow Controller based on K22F Chip

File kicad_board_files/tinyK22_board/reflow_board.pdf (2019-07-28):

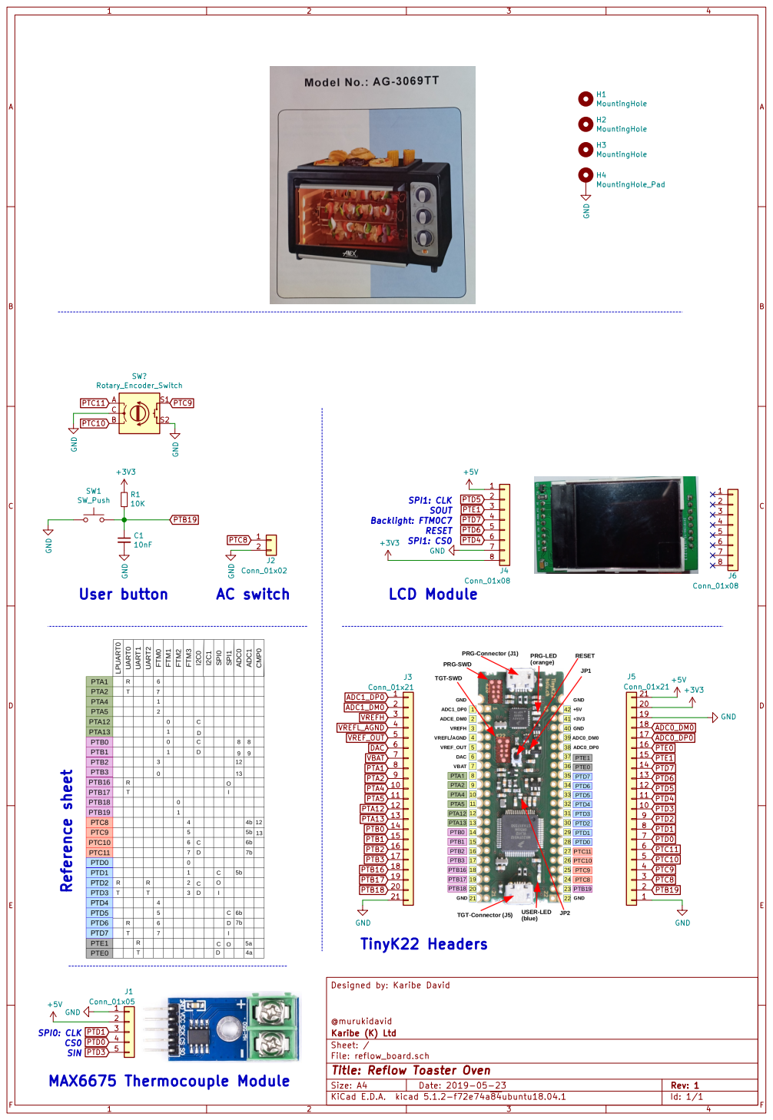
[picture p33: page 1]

AC switch Reference sheet

Designed by: Karibe David

@murukidavid
File: reflow_board.sch Sheet: / Karibe (K) Ltd

Id: 1/1 Title: Reflow Toaster Oven

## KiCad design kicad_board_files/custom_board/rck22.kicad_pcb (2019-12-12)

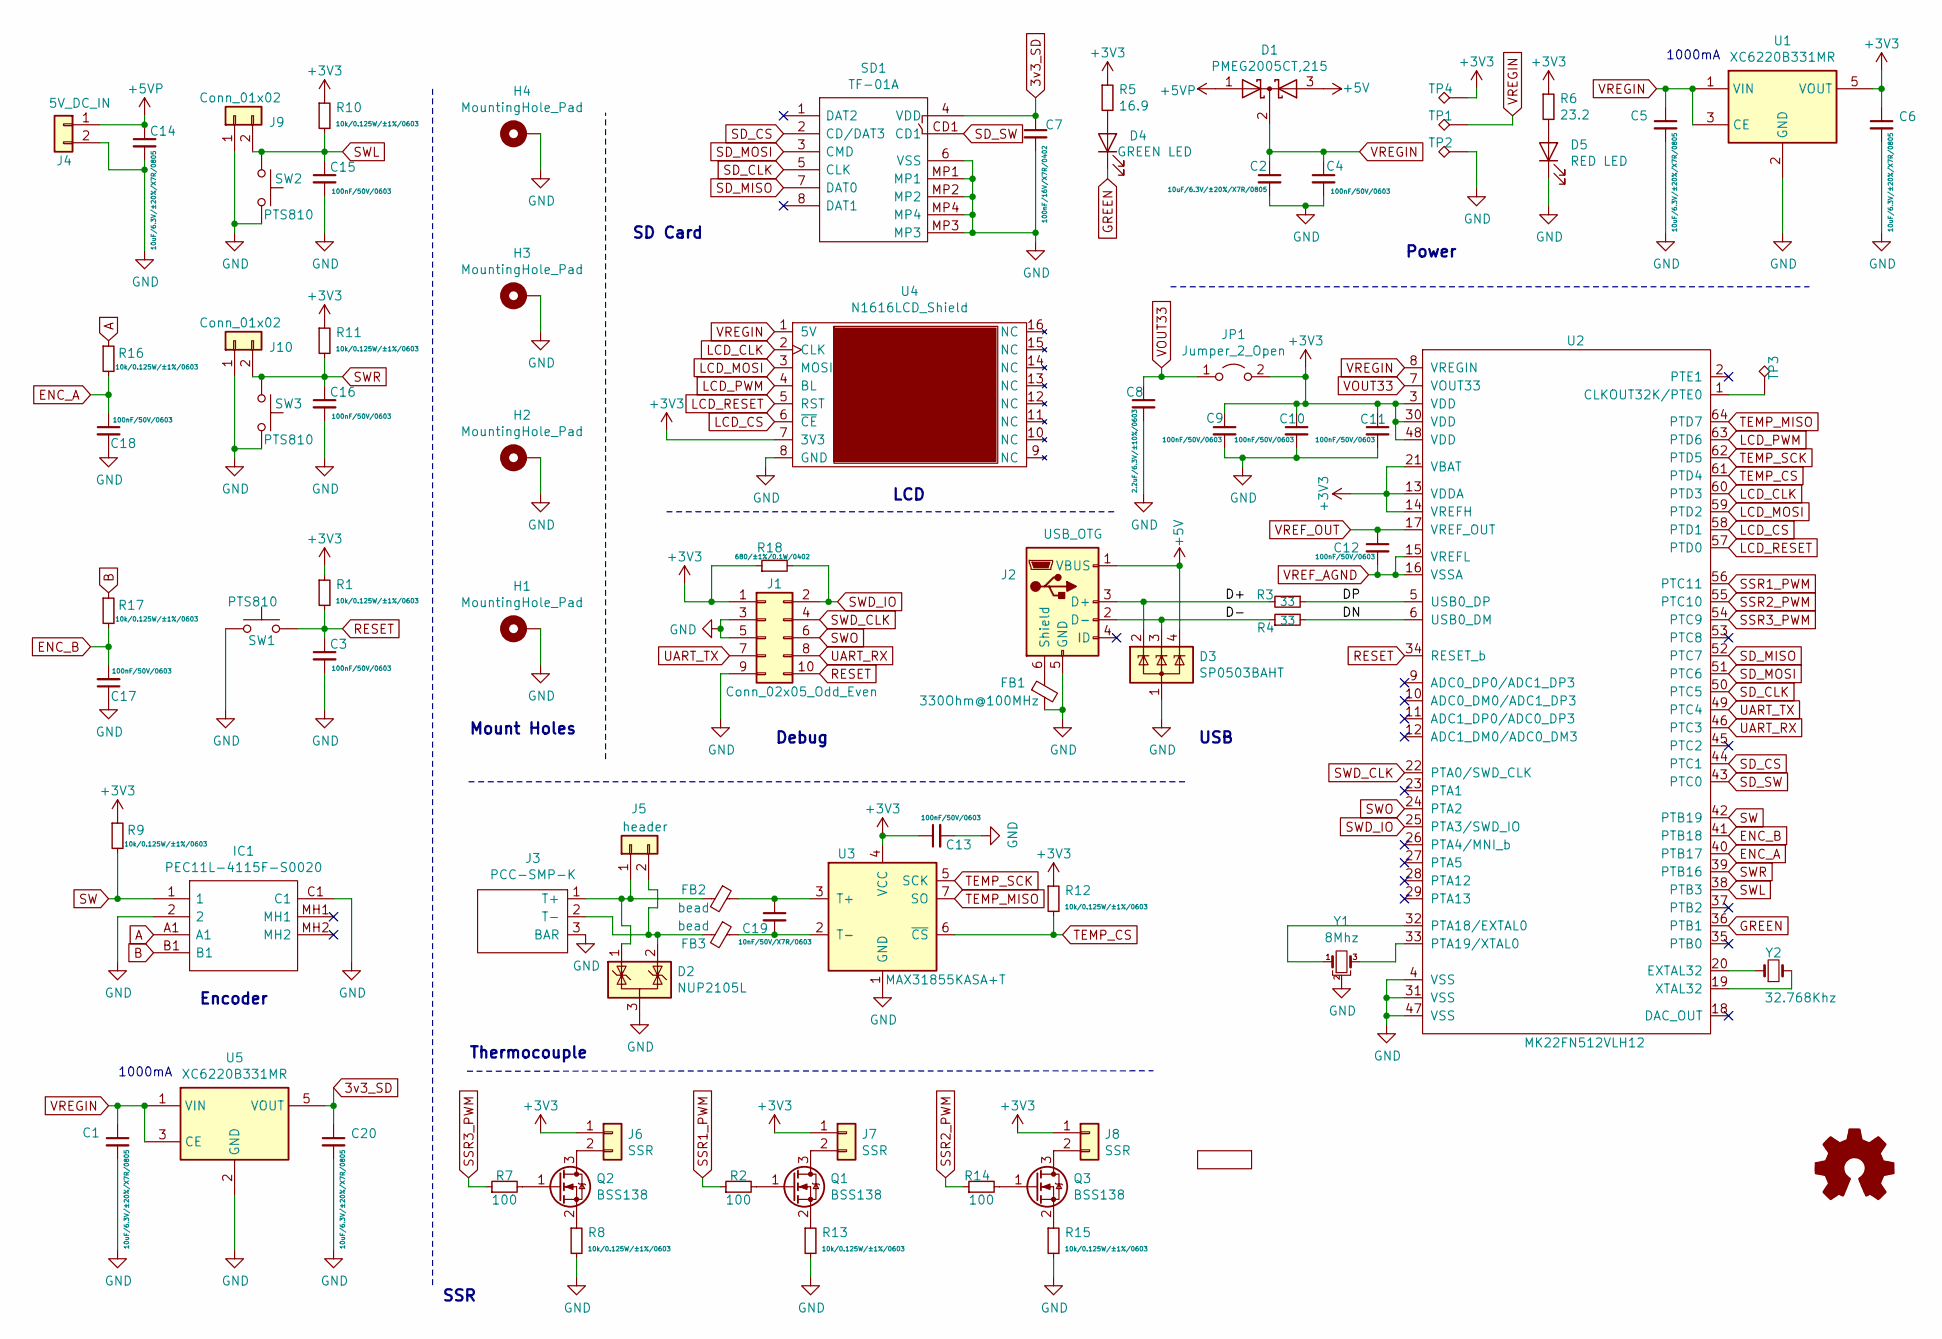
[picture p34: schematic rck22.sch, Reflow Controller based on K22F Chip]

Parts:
C1, C2, C5, C6, C14, C20: 10uF/6.3V/±20%/X7R/0805; C_0805_2012Metric; Mfr. # GRM21BR70J106KA73L; LCSC # C162423
C3, C4, C9, C10, C11, C12, C13, C15, C16, C17, C18: 100nF/50V/0603; C_0603_1608Metric; Mfr. # GRM188R71H104KA93D; LCSC # C77055
C7: 100nF/16V/X7R/0402; C_0402_1005Metric; Mfr. # GCM155R71C104KA55D; LCSC # C85857
C8: 2.2uF/6.3V/±10%/0603; C_0603_1608Metric; Mfr. # GCM188R70J225KE22D; LCSC # C126582
C19: 10nF/50V/X7R/0603; C_0603_1608Metric; Mfr. # GRM188R71H103JA01D; LCSC # C77388
D1: PMEG2005CT,215; SOT-23; Mfr. # PMEG2005CT,215; LCSC # C282562
D2: NUP2105L; SOT-23; Mfr. # NUP2105LT1G; LCSC # C14486
D3: SP0503BAHT; SOT-143; Mfr. # SP0503BAHTG; LCSC # C7074
D4: GREEN LED; LED_0603_1608Metric; Mfr. # ORH-G36G; LCSC # C205443
D5: RED LED; LED_0603_1608Metric; Mfr. # ORH-B36G; LCSC # C193191
FB1: 330Ohm@100MHz; L_0805_2012Metric; Mfr. # MPZ2012S331AT000; LCSC # C76819
FB2, FB3: bead; L_0603_1608Metric; Mfr. # BLM18PG471SN1D; LCSC # C97853
H1, H2, H3, H4: MountingHole_Pad; MountingHole_2.5mm_Pad_Via
IC1: PEC11L-4115F-S0020; PEC11L4115FS0020; Mfr. # PEC11L-4115F-S0020; LCSC # C143799
J1: Conn_02x05_Odd_Even; PinHeader_2x05_P1.27mm_Vertical_SMD; Mfr. # 20021221-00010C4LF; LCSC # C180221
J2: USB_OTG; USB_Micro-B_Molex_47346-0001; Mfr. # 47346-0001; LCSC # C132560
J3: PCC-SMP-K
J4: 5V_DC_IN; JST_PH_S2B-PH-K_1x02_P2.00mm_Horizontal; Mfr. # S2B-PH-K(LF)(SN); LCSC # C265016
J5: header; TerminalBlock_Dinkle_DT-55-B01X-02_P10.00mm
J6, J7, J8: SSR; TerminalBlock_Phoenix_MKDS-1,5-2_1x02_P5.00mm_Horizontal; Mfr. # DB301V-5.0-2P; LCSC # C395882
J9, J10: Conn_01x02; PinSocket_2x01_P2.54mm_Vertical; Mfr. # C49661; LCSC # C49661
JP1: Jumper_2_Open; SolderJumper-2_P1.3mm_Open_RoundedPad1.0x1.5mm
L1: karibe_logo
Q1, Q2, Q3: BSS138; SOT-23; Mfr. # BSS138; LCSC # C52895
R1, R8, R9, R10, R11, R12, R13, R15, R16, R17: 10k/0.125W/±1%/0603; R_0603_1608Metric; Mfr. # MR06X1002FTL; LCSC # C304415
R2, R7, R14: 100; R_0603_1608Metric; Mfr. # RC0603FR-07100RL; LCSC # C105588
R3, R4: 33; R_0402_1005Metric; Mfr. # RC0402FR-0733RL; LCSC # C138002
R5: 16.9; R_0603_1608Metric; Mfr. # RCT0316R9FLF; LCSC # C177850
R6: 23.2; R_0603_1608Metric; Mfr. # AC0603FR-0723R2L; LCSC # C227725
R18: 680/±1%/0.1W/0402; R_0402_1005Metric; Mfr. # RK73H1ETTP6800F; LCSC # C159998
SD1: TF-01A; TF01A; Manufacturer_Part_Number TF-01A
SW1, SW2, SW3: PTS810; SW_SPST_PTS810; Mfr. # PTS810SJG250SMTRLFS; LCSC # C221895
TP1, TP3: 5003; TestPoint_Loop_D1.80mm_Drill1.0mm_Beaded; Mfr. # 5003; LCSC # C238124
TP2: 5001; TestPoint_Loop_D1.80mm_Drill1.0mm_Beaded; Mfr. # 5001; LCSC # C238122
TP4: 5002; TestPoint_Loop_D1.80mm_Drill1.0mm_Beaded; Mfr. # 5002; LCSC # C238123
U1, U5: XC6220B331MR; SOT-23-5; Mfr. # XC6220B331MR-G; LCSC # C86534
U2: MK22FN512VLH12; LQFP-64_10x10mm_P0.5mm; Mfr. # MK22FN512VLH12
U3: MAX31855KASA+T; SOIC-8_3.9x4.9mm_P1.27mm; Mfr. # MAX31855KASA+T; LCSC # C52028
U4: N1616LCD_Shield; Mfr. # C27438; LCSC # C27438
Y1: 8Mhz; Resonator_SMD_muRata_CSTxExxV-3Pin_3.0x1.1mm; Mfr. # CSTCE8M00G55A-R0; LCSC # C91587
Y2: 32.768Khz; Crystal_SMD_2012-2Pin_2.0x1.2mm; Mfr. # SC-20S; LCSC # C97607

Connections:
3v3_SD: C7.1, C20.1, SD1.4 (VDD), U5.5 (VOUT)
+3V3: C6.1, C9.1, C10.1, C11.1, C13.1, J1.1, J6.1, J7.1, J8.1, JP1.2 (B), R1.1, R5.1, R6.1, R9.1, R10.1, R11.1, R12.1, R18.1, TP4.1, U1.5 (VOUT), U2.3 (VDD), U2.13 (VDDA), U2.14 (VREFH), U2.21 (VBAT), U2.30 (VDD), U2.48 (VDD), U3.4 (VCC), U4.7 (3V3)
+5V: D1.3 (A), D3.4 (K), J2.1 (VBUS)
+5VP: C14.1, D1.1 (A), J4.1
/D+: D3.2 (K), J2.3 (D+), R3.2
/D-: D3.3 (K), J2.2 (D-), R4.1
/DN: R4.2, U2.6 (USB0_DM)
/DP: R3.1, U2.5 (USB0_DP)
A: IC1.A1, R16.1
B: IC1.B1, R17.1
ENC_A: C18.1, R16.2, U2.40 (PTB17)
ENC_B: C17.2, R17.2, U2.41 (PTB18)
GND: C1.2, C2.2, C3.2, C4.2, C5.2, C6.2, C7.2, C8.2, C9.2, C10.2, C11.2, C13.2, C14.2, C15.2, C16.2, C17.1, C18.2, C20.2, D2.3 (A), D3.1 (A), D5.1 (K), FB1.2, H1.1, H2.1, H3.1, H4.1, IC1.2, IC1.C1, J1.3, J1.5, J1.9, J2.5 (GND), J3.3 (BAR), J4.2, J9.1, J10.1, R8.2, R13.2, R15.2, SD1.6 (VSS), SD1.MP1, SD1.MP2, SD1.MP3, SD1.MP4, SW1.1, SW2.2, SW3.2, TP2.1, U1.2 (GND), U2.4 (VSS), U2.31 (VSS), U2.47 (VSS), U3.1 (GND), U4.8 (GND), U5.2 (GND), Y1.2
GREEN: D4.1 (K), U2.36 (PTB1)
LCD_CLK: U2.60 (PTD3), U4.2 (CLK)
LCD_CS: U2.58 (PTD1), U4.6 (~CE)
LCD_MOSI: U2.59 (PTD2), U4.3 (MOSI)
LCD_PWM: U2.63 (PTD6), U4.4 (BL)
LCD_RESET: U2.57 (PTD0), U4.5 (RST)
unnamed: C19.1, FB2.1, U3.3 (T+)
unnamed: C19.2, FB3.1, U3.2 (T-)
unnamed: D2.1 (K), FB2.2, J3.1 (T+), J5.1
unnamed: D2.2 (K), FB3.2, J3.2 (T-), J5.2
unnamed: D4.2 (A), R5.2
unnamed: D5.2 (A), R6.2
unnamed: FB1.1, J2.6 (Shield)
unnamed: J6.2, Q2.3 (D)
unnamed: J7.2, Q1.3 (D)
unnamed: J8.2, Q3.3 (D)
unnamed: Q1.1 (G), R2.2
unnamed: Q1.2 (S), R13.1
unnamed: Q2.1 (G), R7.2
unnamed: Q2.2 (S), R8.1
unnamed: Q3.1 (G), R14.2
unnamed: Q3.2 (S), R15.1
unnamed: TP3.1, U2.1 (CLKOUT32K/PTE0)
unnamed: U2.19 (XTAL32), Y2.2
unnamed: U2.20 (EXTAL32), Y2.1
unnamed: U2.32 (PTA18/EXTAL0), Y1.1
unnamed: U2.33 (PTA19/XTAL0), Y1.3
RESET: C3.1, J1.10, R1.2, SW1.2, U2.34 (RESET_b)
SD_CLK: SD1.5 (CLK), U2.50 (PTC5)
SD_CS: SD1.2 (CD/DAT3), U2.44 (PTC1)
SD_MISO: SD1.7 (DAT0), U2.52 (PTC7)
SD_MOSI: SD1.3 (CMD), U2.51 (PTC6)
SD_SW: SD1.CD1, U2.43 (PTC0)
SSR1_PWM: R2.1, U2.56 (PTC11)
SSR2_PWM: R14.1, U2.55 (PTC10)
SSR3_PWM: R7.1, U2.54 (PTC9)
SW: IC1.1, R9.2, U2.42 (PTB19)
SWD_CLK: J1.4, U2.22 (PTA0/SWD_CLK)
SWD_IO: J1.2, R18.2, U2.25 (PTA3/SWD_IO)
SWL: C15.1, J9.2, R10.2, SW2.1, U2.38 (PTB3)
SWO: J1.6, U2.24 (PTA2)
SWR: C16.1, J10.2, R11.2, SW3.1, U2.39 (PTB16)
TEMP_CS: R12.2, U2.61 (PTD4), U3.6 (~CS~)
TEMP_MISO: U2.64 (PTD7), U3.7 (SO)
TEMP_SCK: U2.62 (PTD5), U3.5 (SCK)
UART_RX: J1.8, U2.46 (PTC3)
UART_TX: J1.7, U2.49 (PTC4)
VOUT33: C8.1, JP1.1 (A), U2.7 (VOUT33)
VREF_AGND: C12.2, U2.15 (VREFL), U2.16 (VSSA)
VREF_OUT: C12.1, U2.17 (VREF_OUT)
VREGIN: C1.1, C2.1, C4.1, C5.1, D1.2 (K), TP1.1, U1.1 (VIN), U1.3 (CE), U2.8 (VREGIN), U4.1 (5V), U5.1 (VIN), U5.3 (CE)

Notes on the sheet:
Debug
Encoder
LCD
Power
Thermocouple
USB
Mount Holes
1000mA
SSR
SD Card

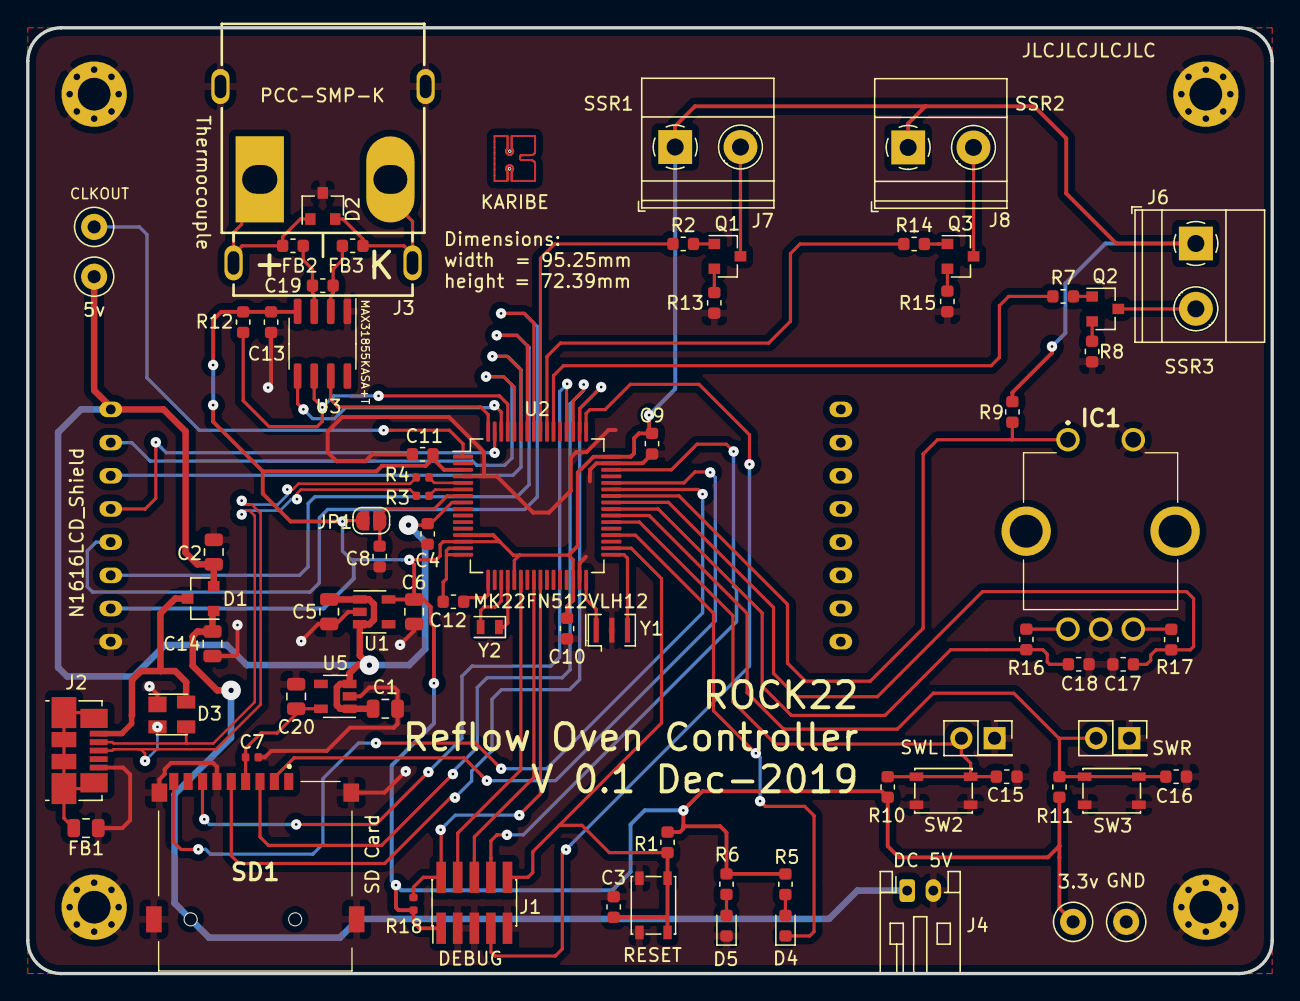
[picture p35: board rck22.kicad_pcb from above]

Board: 2 copper layers, 95.3 x 72.4 mm, 81 parts (1 on the bottom side), 64 nets.

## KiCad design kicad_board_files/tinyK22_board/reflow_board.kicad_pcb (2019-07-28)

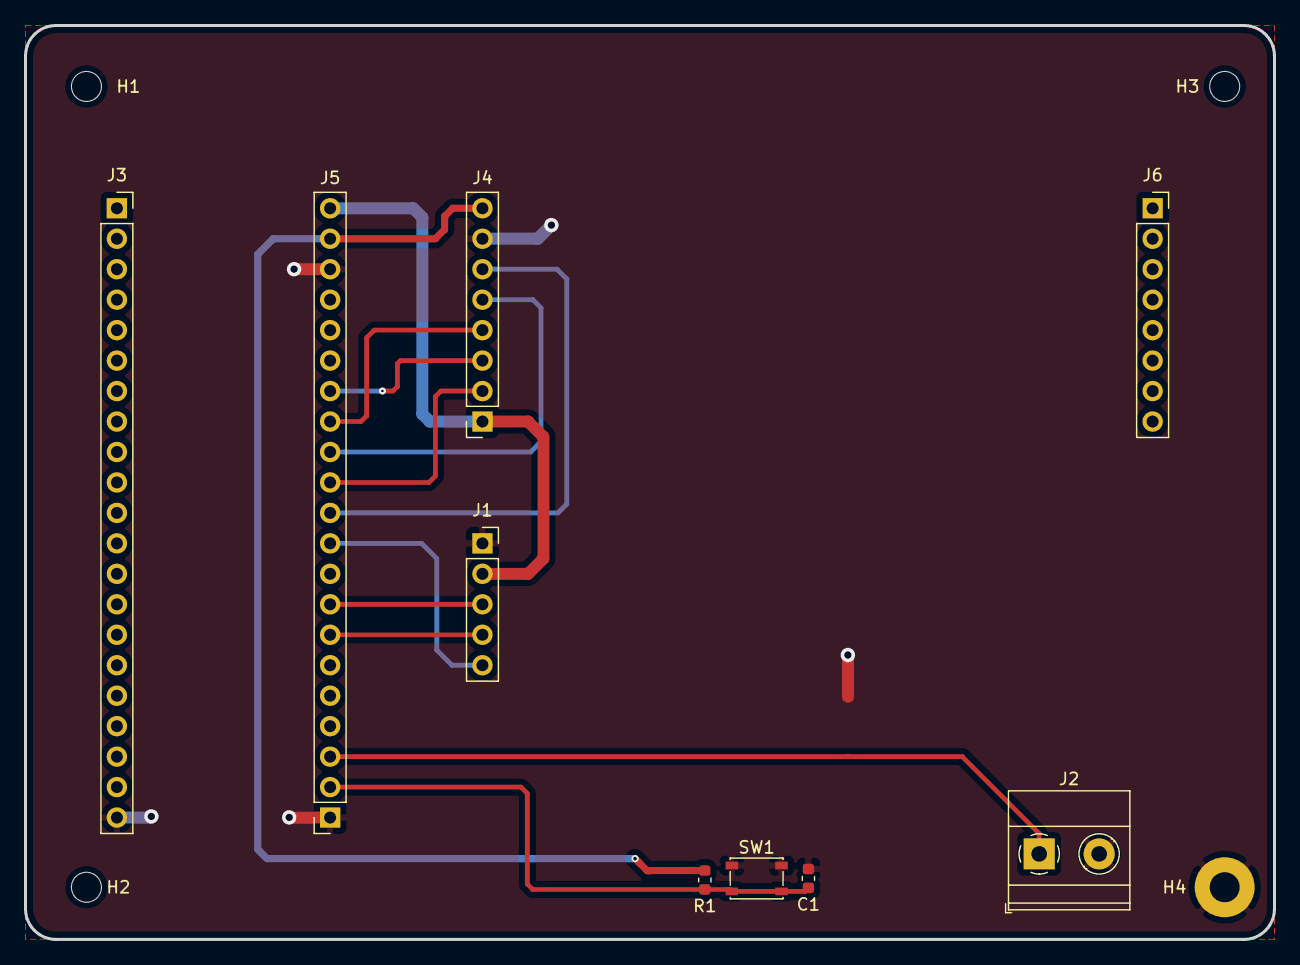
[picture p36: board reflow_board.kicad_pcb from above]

Board: 2 copper layers, 104.1 x 76.2 mm, 13 parts (0 on the bottom side), 13 nets.

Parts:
C1: 10nF; C_0603_1608Metric
H1, H2, H3: MountingHole; MountingHole_2.5mm
H4: MountingHole_Pad; MountingHole_2.5mm_Pad
J1: Conn_01x05; PinSocket_1x05_P2.54mm_Vertical
J2: Conn_01x02; TerminalBlock_Phoenix_MKDS-1,5-2_1x02_P5.00mm_Horizontal
J3, J5: Conn_01x21; PinSocket_1x21_P2.54mm_Vertical
J4, J6: Conn_01x08; PinSocket_1x08_P2.54mm_Vertical
R1: 10K; R_0603_1608Metric
SW1: SW_Push; SW_SPST_PTS810

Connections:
+3V3: J4.8, J5.20, R1.2
+5V: J1.2, J4.1, J5.21
GND: C1.2, H4.1, J1.1, J2.2, J3.21, J4.7, J5.1, J5.19, SW1.1
PTB19: C1.1, J5.2, R1.1, SW1.2
PTC8: J2.1, J5.3
PTD0: J1.4, J5.7
PTD1: J1.3, J5.8
PTD3: J1.5, J5.10
PTD4: J4.6, J5.11
PTD5: J4.2, J5.12
PTD6: J4.5, J5.13
PTD7: J4.4, J5.14
PTE1: J4.3, J5.15

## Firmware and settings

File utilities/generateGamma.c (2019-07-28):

#include <stdio.h>
#include <math.h>
#include<stdlib.h>

      
void printPWMGammaTable(double PWMgamma, int maxValue){
	//double PWMgamma   = 1.8; // Correction factor
	int max_in  = 100, // Top end of INPUT range
		max_out = 100; // Top end of OUTPUT range
	printf("\n[C code]\n//Gamma = %f\nconst uint8_t gamma1_8PWM[] = {",PWMgamma);
	for(int i=0; i<=max_in; i++) {
		if(i > 0) printf(",");
		if((i & 15) == 0) printf("\n  ");

		printf("%3d",(int)(pow((double)i / (double)max_in, PWMgamma) * max_out + 0.5));
	}
	printf("\n };\n[/C code]\n\n");
}

void printRGBGammaTable(double RGBgamma, int maxValue){
	//double gamma   = 2.2; // Correction factor
	int max_in  = 255, // Top end of INPUT range
		max_out = 255; // Top end of OUTPUT range
	printf("\n[C code]\n//Gamma = %f\nconst uint8_t gamma2_2[] = {",RGBgamma);
	for(int i=0; i<=max_in; i++) {
		if(i > 0) printf(",");
		if((i & 15) == 0) printf("\n  ");

		printf("%3d",(int)(pow((double)i / (double)max_in, RGBgamma) * max_out + 0.5));
	}
	printf("\n };\n[/C code]\n\n");
}

int main(int argc, char **argv) {
	double factor;
	int maxVal;
	
	if(argc<3){
		printf("Usage: /gamma factor maxValue\nWhere,\n\tfactor is a double between 0 and 3\n\t maxValue is the largest input/output value\n\n");
		return 0;
	}
	
	factor = atof(argv[1]);
	maxVal = atoi(argv[2]);
	if(maxVal==100){
		printPWMGammaTable(factor, maxVal);
	}else{
		printRGBGammaTable(factor, maxVal);
	}
	return 0;
}

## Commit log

2019-05-23 Add initial design for a reflow oven
    Create a KiCad project with schematic and PCB layout for a tinyk22 breakout board
    Add reference documents, datasheets and images
    [38261.stp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]
2019-07-28 Add a custom circuit board
    Add a custom circuit board based on NXP K22F MCU on a separate directory
    Put all images in a separate directory for ease of management
    Update the README file
    [1051620101.step, 38261.stp, CSTCE.step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]
2019-09-07 Add protection to thermocouple input
    Update the thermocouple interface with ferrite beads and filter capacitor
    Add an alternative thermocouple connector other than terminal block
    Add extra SSR lines for the case of multiple heaters
    Replace the 700mA 3.3V regulator with a 1A regulator, and replace its capacitors
    Add 10K series resistors to the rotary encoder ouputs
    Replace buttons with two pin header connectors so as to use momentary switches on the casing
    Reverse UART connection in ARM SWD debug connector
    Tune LED resistors to the datasheet parameters
    Rearrange the schamtic and layout
    Source all components and generate a HTML BOM
    Update the README
    [LED_resistor_tuning.ods, PCC-SMP-K.STEP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]
2019-11-24 Tweak the PCB silkscreen, add main UI graphic
    Add some silkscreen text with version number and Logos
    Add a graphic to be loaded from SD card for the main UI before reflow graph
    Tweak the PCB layout and export new images from the 3D viewer
    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
    [rck22.kicad_pcb, rck22.sch]
2019-11-24 Add htmlpreview.github.io link to a HTML BOM
2019-12-12 touch up the board
    Re-assign some GPIOs to simplify routing
    Mark SMD components as surface mount in their properties
    Re-arrange power connector and status LEDs
    Replace the SD card component with one readily available at LCSC.com
    Add optional on-board SMD PTS810 buttons
    Change some capacitor footprints from 0402 to 0805 to reduce BOM items
    Add more details on the silkscreen: dimensions, jlcpcb customer identifier placeholder e.t.c
    [ROCK22-B_Cu.gbr, ROCK22-B_Mask.gbr, ROCK22-B_SilkS.gbr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]
